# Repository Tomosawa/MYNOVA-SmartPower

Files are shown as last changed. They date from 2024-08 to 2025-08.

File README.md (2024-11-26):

<div id="top">
<p align="center">
  

  <h1 align="center">MYNOVA-SmartPower</h1>
</p>
</div>
<div align="center">








English | [简体中文](README_zh-CN.md) | [日本語](README_ja-JP.md)

</div>

# Introduction

This is an open-source hardware project aimed at creating an intelligent power extraction box for DELL server PSUs. It controls power switching, reads voltage, current, power values, and temperature inputs and displays them on an OLED screen. The device outputs 12V power through DC5.5 and XT60 interfaces for standard 12V devices.

The open-source project includes firmware code for the chip, web-based application code, circuit schematics (Altium Designer and PADS), and PCB Gerber files. Additionally, 3D files of the casing are provided for 3D printing.

Completed product can be seen in the following image:

<center>

<p float="left">
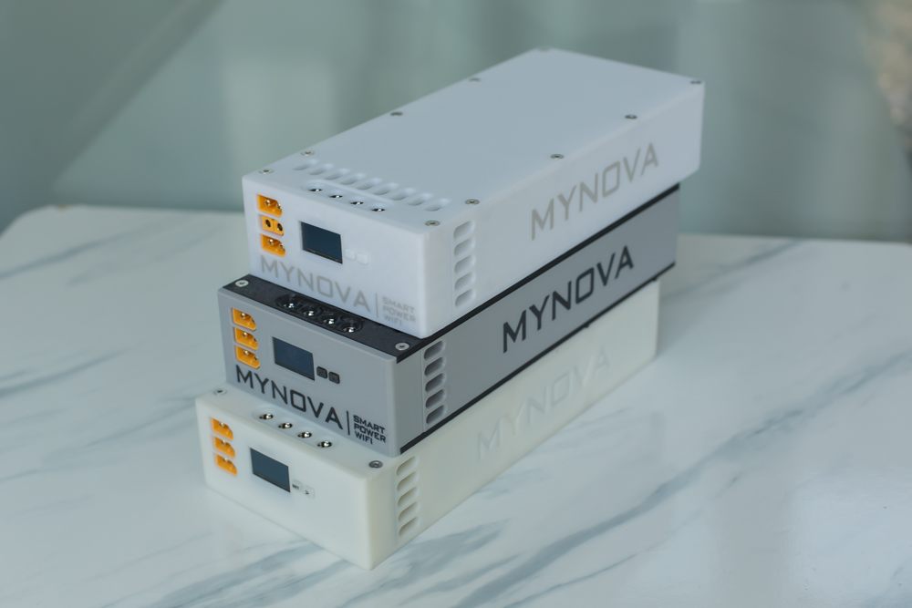
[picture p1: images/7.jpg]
  
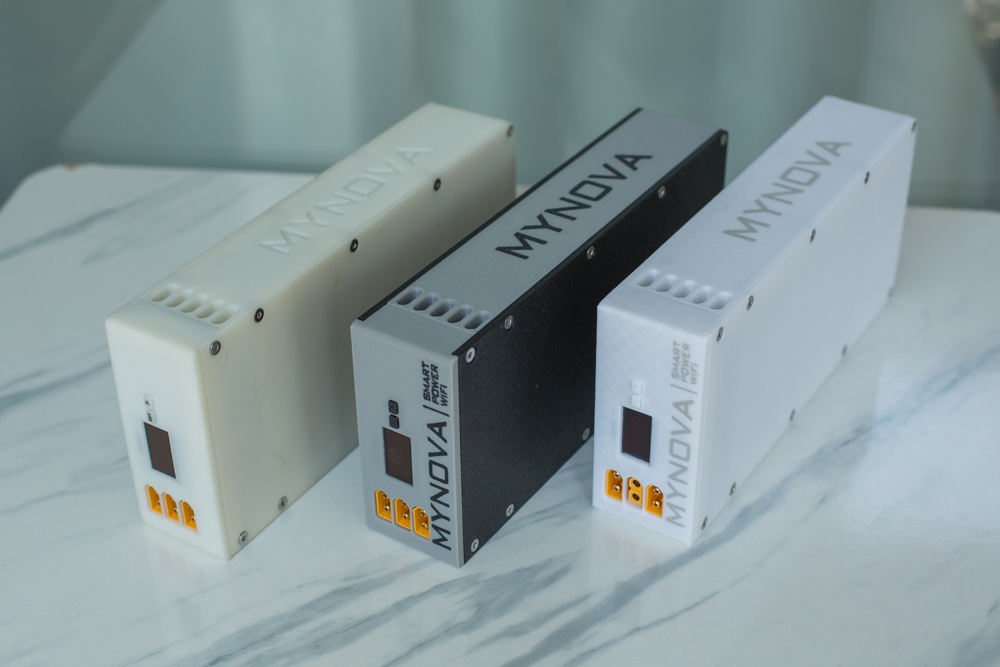
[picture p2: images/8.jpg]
  
</p>
<p float="left">
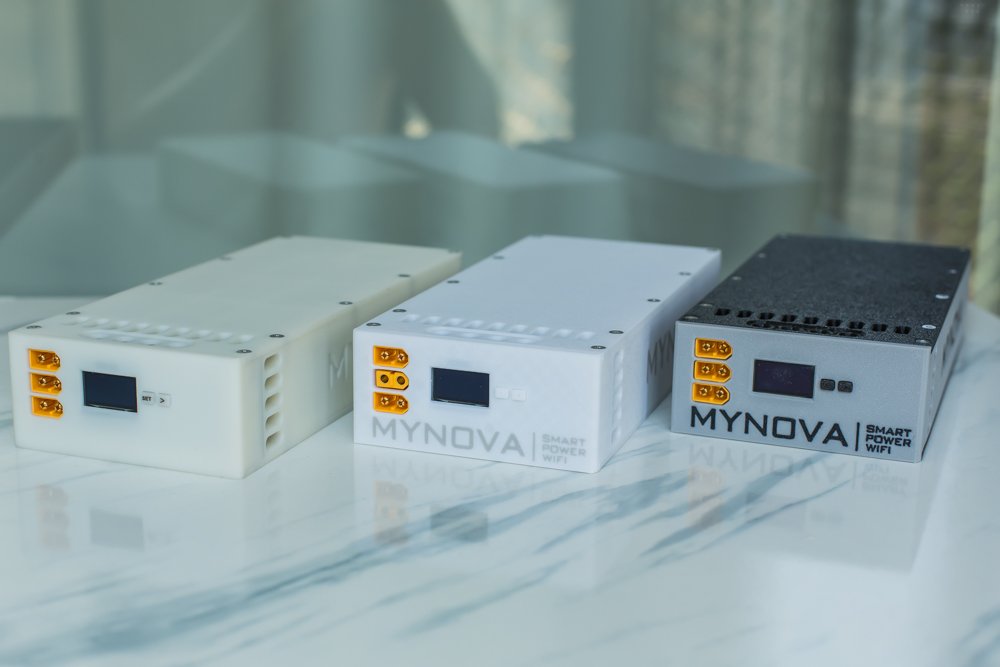
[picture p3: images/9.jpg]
  
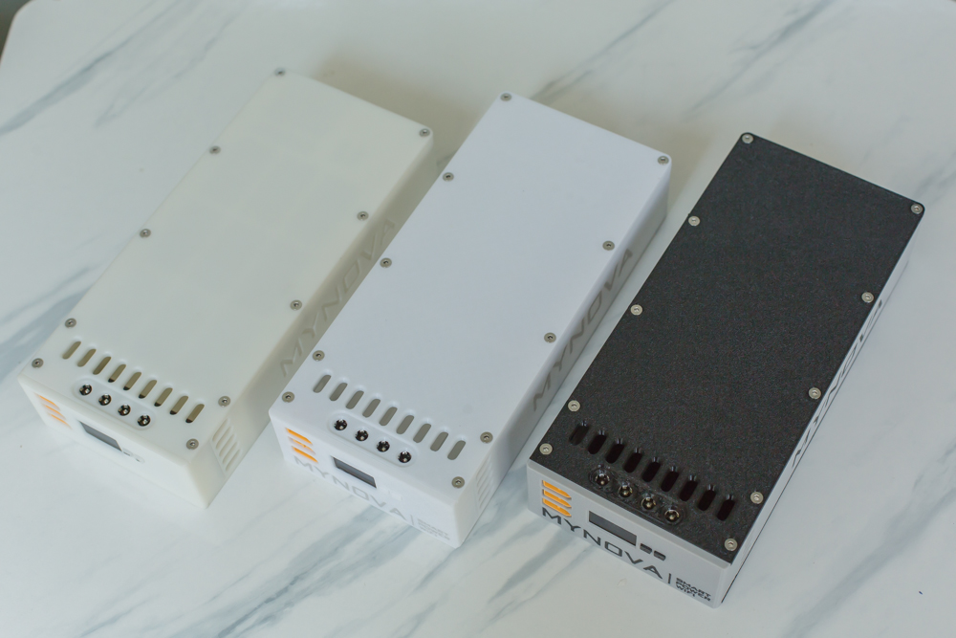
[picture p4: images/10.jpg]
  
</p>
<p float="left">
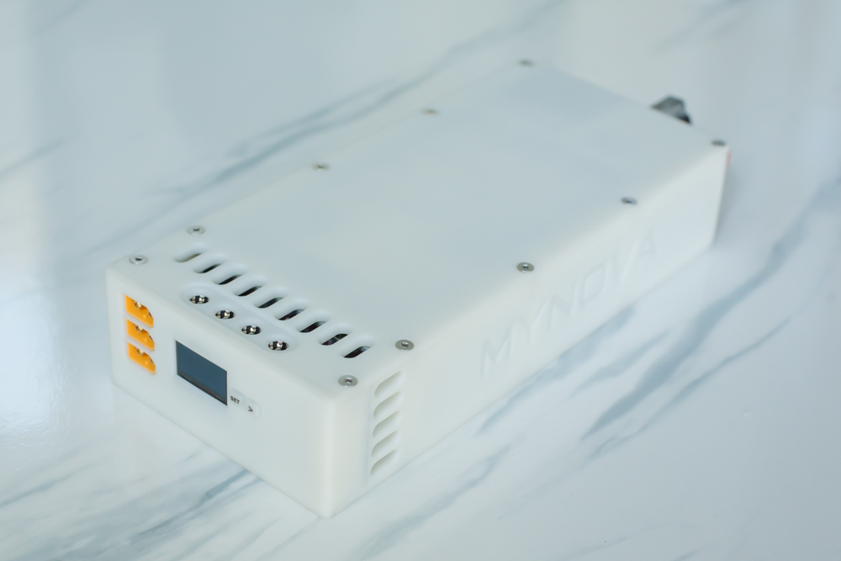
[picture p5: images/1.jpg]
  
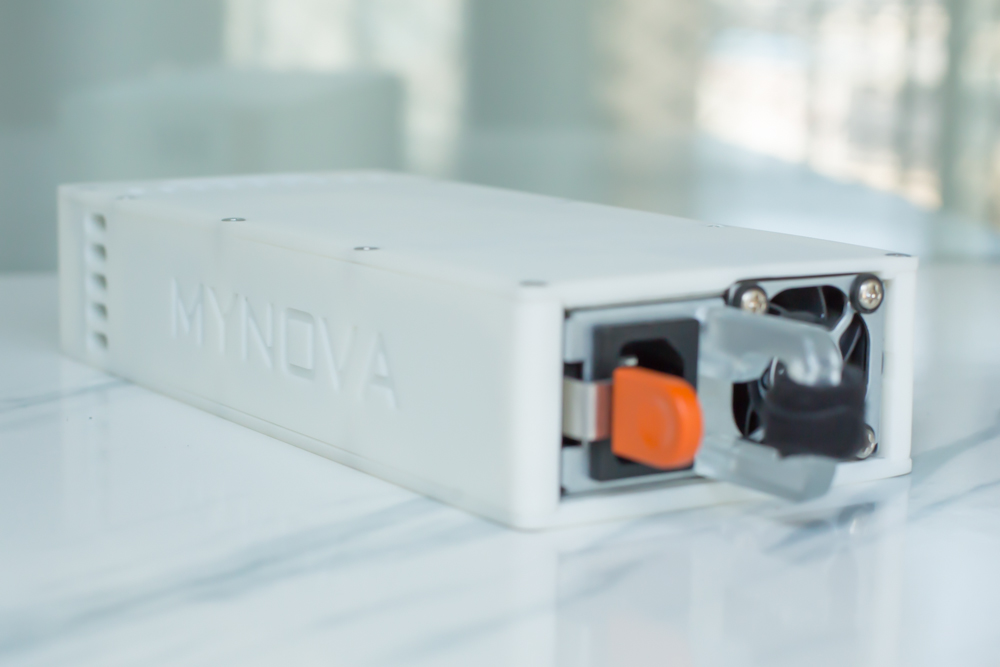
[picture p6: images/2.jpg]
  
</p>
<p float="left">
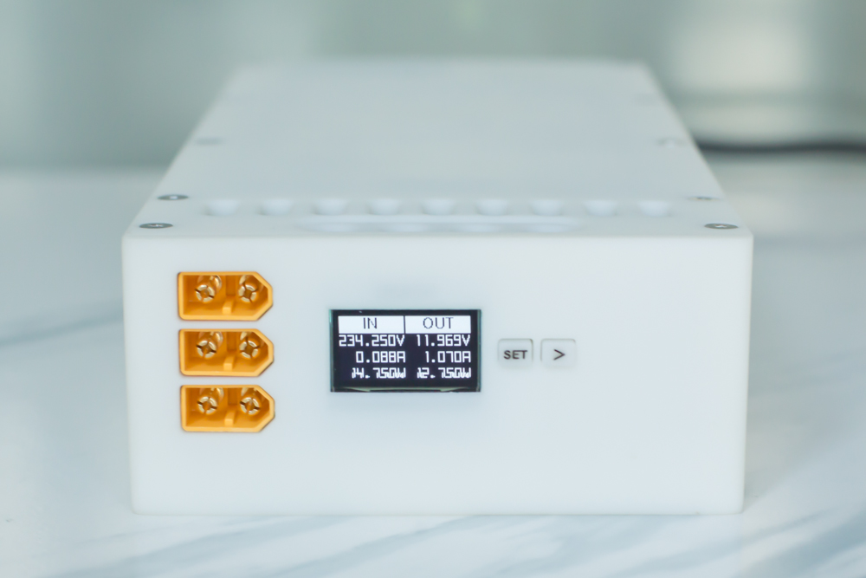
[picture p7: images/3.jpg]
  
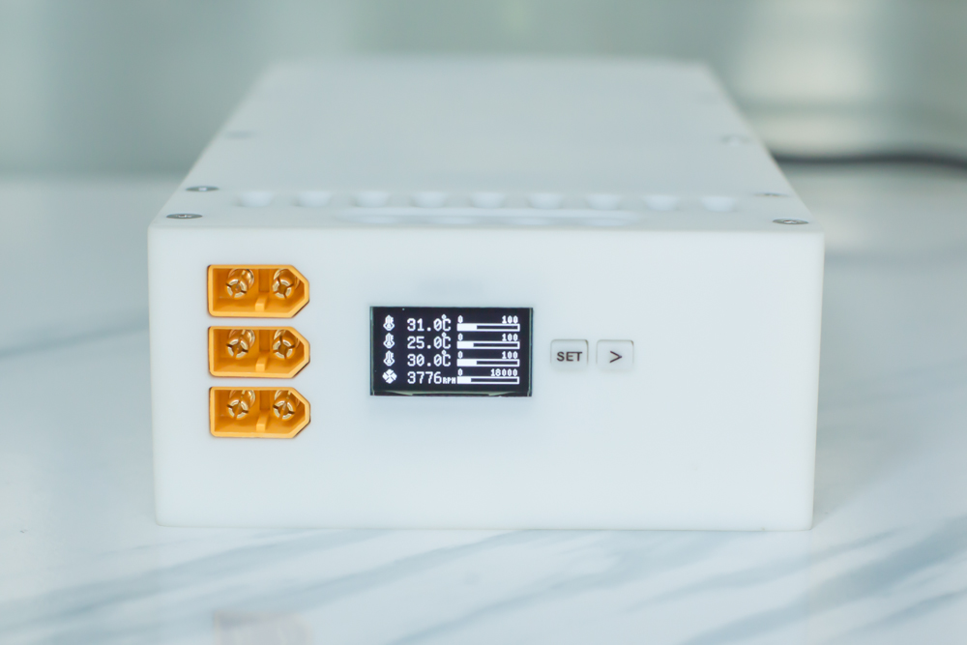
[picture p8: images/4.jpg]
  
</p>
<p float="left">
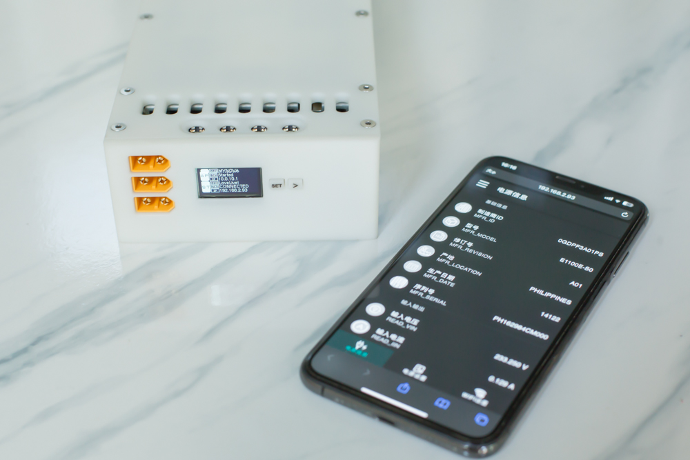
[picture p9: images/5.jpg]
  
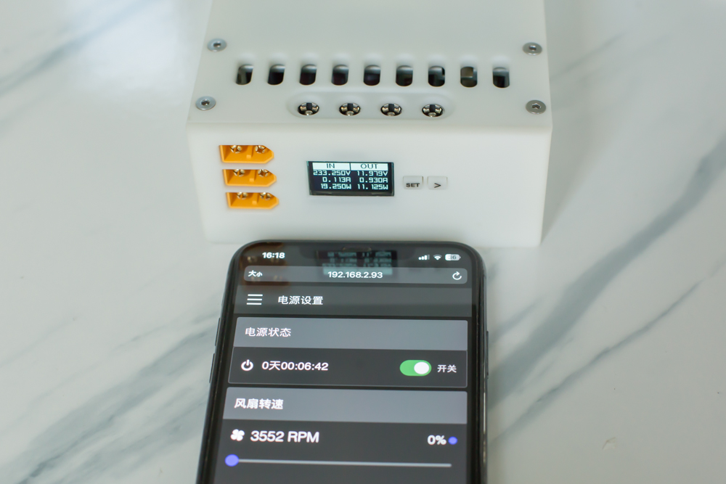
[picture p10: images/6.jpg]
  
</p>

</center>

## Features

- Control power on and off.
- Read and display input, output voltage, current, and power values.
- Read power supply temperature.
- Set fan speed (currently ineffective, overridden by the PSU itself).
- WiFi connectivity to view data via web interface by entering IP on mobile or computer.
- Control power on and off via web interface.

## New Features in V1.1 (20241126)
- Compatibility with E495E-S1 and E750E-S1 power supplies
- Added a settings page on the device end: Access by long-pressing the right key on the network page.
- Support for toggling WIFI on/off, hotspot on/off, and screen brightness settings
- Support for setting the device to automatically power on after being plugged in
- Countdown automatic shutdown feature
- Timed on/off feature, supporting time period settings for on/off, individual on or off, and repeat cycle strategy setup
- Conditional shutdown feature, which shuts down the device when the input or output current or power exceeds or falls below a certain value.

## Supported Chips

- ESP32-S3-WROOM-N16
- ESP32-S3-WROOM-N8

Or chips from the ESP32-S3 series. Depending on flash capacity of the chip, define partition table before download firmware.

## Tested PSU

This firmware has been tested on the following DELL PSU models:
- F495E-S0
- E750E-S0
- F750E-S0
- D750E-S2
- E1100E-S0
- L1100E-S0
- D2000E-S2(EPP)
- E495E-S1(EPP)
- E750E-S1(EPP)

Other models should be similar; further testing required as I lack additional models.

## Directory Structure

- MYNOVA_POWER: Firmware code for the chip.
- ESPVue: Web-related application code.
- partitions: Partition table files.
- Hardware: Hardware datasheet, including circuit schematics, design files for Altium Designer and PADS, as well as PCB Gerber files.
- 3DModels: 3D model files for the casing, including STL and editable STEP files.

## Compilation Environment

- Firmware: Arduino IDE 1.8.19
- Web: Node.js v20.15.1

## Firmware Dependencies

- Install ESP32 official development board (recommended V2.0.11 to avoid compilation failures).
- Install U8g2lib.
- Install ESPAsyncWebServer server component.
- Install ArduinoJson library.
- Install ESP32TimerInterrupt library.

## Firmware Flashing Method

1. Depending on the flash size of your ESP32-S3 chip (16MB or 8MB), download the corresponding bin file from the [Release](https://github.com/Tomosawa/MYNOVA-SmartPower/releases) page.
2. Download the official [flash download tools](https://www.espressif.com/en/support/download/other-tools) or use the [esptool.py](https://github.com/espressif/esptool) command line tool.
3. Select the appropriate `.bin` firmware file and set the flash offset address to `0x0000`.
4. Do not check the `DoNotChgBin` option, then click start to begin the flashing process.

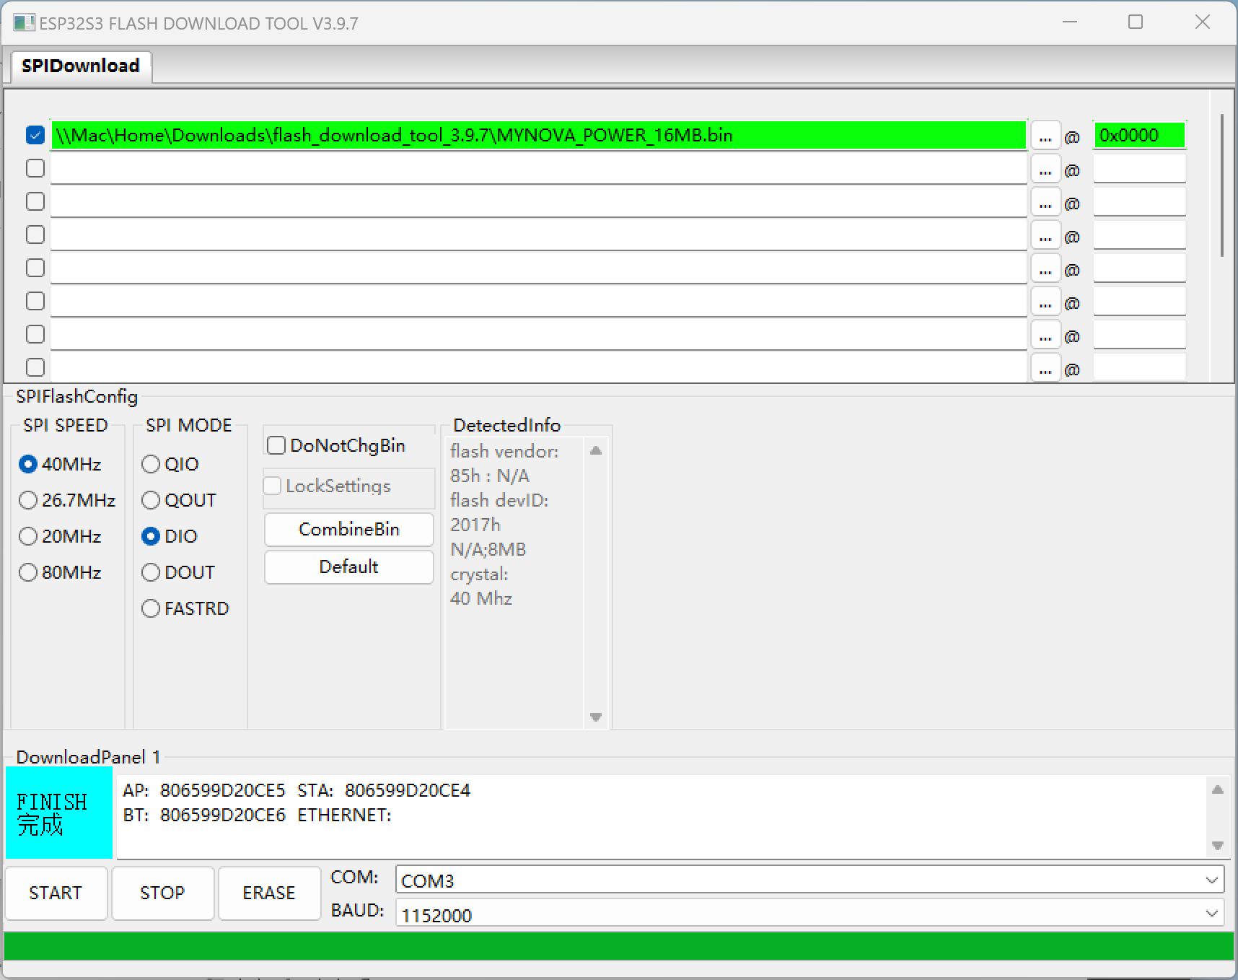
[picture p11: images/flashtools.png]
flashdownloadtools


## Contribution Guidelines

Contributions to this project are welcome. Please follow these guidelines:
- Fork the repository and create your feature branch.
- Commit your changes and push to your fork.
- Submit a Pull Request.

## Copyright Statement

This project is prohibited for any commercial use and is intended for learning and DIY purposes only.

## License [LICENSE](LICENSE)

This project is licensed under the [GPLv3](LICENSE). [GPLv3 (GNU General Public License version 3)](LICENSE) is a free, open-source software license that guarantees users the freedoms to run, study, share, and modify the software.
The complete text of the [GPLv3](LICENSE) license is included in the [LICENSE](LICENSE) file of this project. Before using, modifying, or distributing the code of this project, make sure you have read and understood the entire [GPLv3](LICENSE) license.

## Acknowledgments

- [Multibutton](https://github.com/0x1abin/MultiButton)

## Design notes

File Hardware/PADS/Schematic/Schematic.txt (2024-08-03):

*PADS-LOGIC-V9.0-CP936* from EasyEDA Pro
*SCH*
BORDER NAME Altium_A4
*SHT* 2 1_P1 -1 $$$NONE
*TEXT*
9600 4300 90 0 167 10 0 "Regular Times New Roman"
IO2
1650 3050 0 12 278 10 0 "Regular 宋体"
电源输入部分
8950 3100 0 12 278 10 0 "Regular 宋体"
单片机部分
4550 3100 0 12 278 10 0 "Regular 宋体"
开关及状态指示
1750 1950 0 12 278 10 0 "Regular 宋体"
OLED显示屏
5350 550 0 12 278 10 0 "Regular 宋体"
3.3V供电模块
9400 550 0 12 278 10 0 "Regular 宋体"
输出接口
1700 650 0 12 278 10 0 "Regular 宋体"
螺丝孔
550 2050 0 0 139 10 0 "Regular 宋体"
显示屏HS96L03W2C03需单独买
*LINES*
Altium_A4 LINES 0 0 6 43
CLOSED 5 10 255
0 7600
0 0
11500 0
11500 7600
0 7600
CLOSED 5 10 255
400 7200
400 400
11100 400
11100 7200
400 7200
OPEN 2 10 255
10781 0
10781 400
OPEN 2 10 255
10781 7200
10781 7600
OPEN 2 10 255
0 5700
400 5700
OPEN 2 10 255
11100 5700
11500 5700
359 200 0 12 125 10 0 "Regular Verdana"
1
359 7400 0 12 125 10 0 "Regular Verdana"
1
1078 200 0 12 125 10 0 "Regular Verdana"
2
1078 7400 0 12 125 10 0 "Regular Verdana"
2
1797 200 0 12 125 10 0 "Regular Verdana"
3
1797 7400 0 12 125 10 0 "Regular Verdana"
3
2516 200 0 12 125 10 0 "Regular Verdana"
4
2516 7400 0 12 125 10 0 "Regular Verdana"
4
3234 200 0 12 125 10 0 "Regular Verdana"
5
3234 7400 0 12 125 10 0 "Regular Verdana"
5
3953 200 0 12 125 10 0 "Regular Verdana"
6
3953 7400 0 12 125 10 0 "Regular Verdana"
6
4672 200 0 12 125 10 0 "Regular Verdana"
7
4672 7400 0 12 125 10 0 "Regular Verdana"
7
5391 200 0 12 125 10 0 "Regular Verdana"
8
5391 7400 0 12 125 10 0 "Regular Verdana"
8
6109 200 0 12 125 10 0 "Regular Verdana"
9
6109 7400 0 12 125 10 0 "Regular Verdana"
9
6828 200 0 12 125 10 0 "Regular Verdana"
10
6828 7400 0 12 125 10 0 "Regular Verdana"
10
7547 200 0 12 125 10 0 "Regular Verdana"
11
7547 7400 0 12 125 10 0 "Regular Verdana"
11
8266 200 0 12 125 10 0 "Regular Verdana"
12
8266 7400 0 12 125 10 0 "Regular Verdana"
12
8984 200 0 12 125 10 0 "Regular Verdana"
13
8984 7400 0 12 125 10 0 "Regular Verdana"
13
9703 200 0 12 125 10 0 "Regular Verdana"
14
9703 7400 0 12 125 10 0 "Regular Verdana"
14
10422 200 0 12 125 10 0 "Regular Verdana"
15
10422 7400 0 12 125 10 0 "Regular Verdana"
15
11141 200 0 12 125 10 0 "Regular Verdana"
16
11141 7400 0 12 125 10 0 "Regular Verdana"
16
200 950 0 12 125 10 0 "Regular Verdana"
D
11300 950 0 12 125 10 0 "Regular Verdana"
D
200 2850 0 12 125 10 0 "Regular Verdana"
C
11300 2850 0 12 125 10 0 "Regular Verdana"
C
200 4750 0 12 125 10 0 "Regular Verdana"
B
11300 4750 0 12 125 10 0 "Regular Verdana"
B
200 6650 0 12 125 10 0 "Regular Verdana"
A
11300 6650 0 12 125 10 0 "Regular Verdana"
A
0 -400 0 0 139 10 0 "Regular Times New Roman"
ModifiedDate : 2024/6/10
0 -300 0 0 139 10 0 "Regular Times New Roman"
Author : Tomosawa
0 -200 0 0 139 10 0 "Regular Times New Roman"
Title : 戴尔服务器电源取电板
$$Line1 LINES 0 0 1 0
OPEN 3 10 0
400 2900
2950 2900
2950 7200
$$Line2 LINES 0 0 1 0
OPEN 2 10 0
2950 2900
2955 405
$$Line3 LINES 0 0 1 0
OPEN 2 10 0
6850 7200
6850 2900
$$Line4 LINES 0 0 1 0
OPEN 2 10 0
7600 2900
7605 405
$$Line5 LINES 0 0 1 0
OPEN 2 10 0
2955 2905
11100 2900
$$Line6 LINES 0 0 1 0
OPEN 2 10 0
400 1750
2950 1750
*CAEDECAL*
PIN 0 0 100 10 100 10 2 1 0 0 0 1
TIMESTAMP 2024.08.03.20.45.55
"Default Font"
"Default Font"
0 0 0 0 94 6 0 "Regular default"
PART-TYPE
0 0 0 0 94 6 0 "Regular default"
REF-DES
OPEN 2 10 255
0 0
100 0
PIN_1 0 0 100 10 100 10 2 1 0 0 0 1
TIMESTAMP 2024.08.03.20.45.55
"Default Font"
"Default Font"
0 0 0 0 94 6 0 "Regular default"
PART-TYPE
0 0 0 0 94 6 0 "Regular default"
REF-DES
OPEN 2 10 255
0 0
200 0
PIN_2 0 0 100 10 100 10 2 1 0 0 0 1
TIMESTAMP 2024.08.03.20.45.55
"Default Font"
"Default Font"
0 0 0 0 94 6 0 "Regular default"
PART-TYPE
0 0 0 0 94 6 0 "Regular default"
REF-DES
OPEN 2 10 255
0 0
20 0
+12V 0 0 100 10 100 10 2 3 0 1 26 0
TIMESTAMP 2024.08.03.20.45.55
"Default Font"
"Default Font"
0 0 0 0 9 1 0 "Regular default"
PART-TYPE
0 0 0 0 9 1 0 "Regular default"
REF-DES
OPEN 2 10 255
0 0
100 0
OPEN 2 10 255
100 50
100 -50
OPEN 2 10 255
0 0
-0 -0
T0 0 90 2 0 10 0 4 10 -30 0 0 
P-100 0 0 1 0 0 0 0 128
+12VSB 0 0 100 10 100 10 2 3 0 1 26 0
TIMESTAMP 2024.08.03.20.45.55
"Default Font"
"Default Font"
0 0 0 0 9 1 0 "Regular default"
PART-TYPE
0 0 0 0 9 1 0 "Regular default"
REF-DES
OPEN 2 10 255
0 0
100 0
OPEN 2 10 255
100 50
100 -50
OPEN 2 10 255
0 0
-0 -0
T0 0 90 2 0 10 0 4 10 -30 0 0 
P-100 0 0 1 0 0 0 0 128
0603WAF2200T5E 0 0 100 10 100 10 2 1 0 2 0 0
TIMESTAMP 2024.08.03.20.45.55
"Default Font"
"Default Font"
0 0 0 0 14 10 0 "Regular 宋体"
PART-TYPE
0 0 0 0 14 10 0 "Regular 宋体"
REF-DES
CLOSED 5 10 255
-100 40
-100 -40
100 -40
100 40
-100 40
T200 0 0 1 50 10 0 4 110 -30 0 0 PIN
P-100 0 0 1 0 0 0 0 128
T-200 0 0 0 50 10 0 4 110 -30 0 0 PIN
P-100 0 0 1 0 0 0 0 128
100p 0 0 100 10 100 10 2 4 0 2 0 0
TIMESTAMP 2024.08.03.20.45.55
"Default Font"
"Default Font"
0 0 0 0 14 10 0 "Regular 宋体"
PART-TYPE
0 0 0 0 14 10 0 "Regular 宋体"
REF-DES
OPEN 2 10 255
-20 -80
-20 80
OPEN 2 10 255
100 0
20 0
OPEN 2 10 255
20 80
20 -80
OPEN 2 10 255
-20 0
-100 0
T-200 0 0 0 50 10 0 4 110 -30 0 0 PIN
P-100 0 0 1 0 0 0 0 128
T200 0 0 1 50 10 0 4 110 -30 0 0 PIN
P-100 0 0 1 0 0 0 0 128
10114587-001LF 0 0 100 10 100 10 2 1 0 60 0 0
TIMESTAMP 2024.08.03.20.45.55
"Default Font"
"Default Font"
0 0 0 0 9 1 0 "Regular default"
PART-TYPE
0 0 0 0 9 1 0 "Regular default"
REF-DES
CLOSED 5 10 255
-200 1600
-200 -1600
200 -1600
200 1600
-200 1600
T-400 1500 0 0 100 10 0 4 210 -30 0 0 PIN_1
P-100 0 0 1 0 0 0 0 128
T-400 1400 0 0 100 10 0 4 210 -30 0 0 PIN_1
P-100 0 0 1 0 0 0 0 128
T-400 1300 0 0 100 10 0 4 210 -30 0 0 PIN_1
P-100 0 0 1 0 0 0 0 128
T-400 1200 0 0 100 10 0 4 210 -30 0 0 PIN_1
P-100 0 0 1 0 0 0 0 128
T-400 1100 0 0 100 10 0 4 210 -30 0 0 PIN_1
P-100 0 0 1 0 0 0 0 128
T-400 1000 0 0 100 10 0 4 210 -30 0 0 PIN_1
P-100 0 0 1 0 0 0 0 128
T-400 900 0 0 100 10 0 4 210 -30 0 0 PIN_1
P-100 0 0 1 0 0 0 0 128
T-400 800 0 0 100 10 0 4 210 -30 0 0 PIN_1
P-100 0 0 1 0 0 0 0 128
T-400 700 0 0 100 10 0 4 210 -30 0 0 PIN_1
P-100 0 0 1 0 0 0 0 128
T-400 600 0 0 100 10 0 4 210 -30 0 0 PIN_1
P-100 0 0 1 0 0 0 0 128
T-400 500 0 0 100 10 0 4 210 -30 0 0 PIN_1
P-100 0 0 1 0 0 0 0 128
T-400 400 0 0 100 10 0 4 210 -30 0 0 PIN_1
P-100 0 0 1 0 0 0 0 128
T-400 300 0 0 100 10 0 4 210 -30 0 0 PIN_1
P-100 0 0 1 0 0 0 0 128
T-400 200 0 0 100 10 0 4 210 -30 0 0 PIN_1
P-100 0 0 1 0 0 0 0 128
T-400 100 0 0 100 10 0 4 210 -30 0 0 PIN_1
P-100 0 0 1 0 0 0 0 128
T-400 0 0 0 100 10 0 4 210 -30 0 0 PIN_1
P-100 0 0 1 0 0 0 0 128
T-400 -100 0 0 100 10 0 4 210 -30 0 0 PIN_1
P-100 0 0 1 0 0 0 0 128
T-400 -200 0 0 100 10 0 4 210 -30 0 0 PIN_1
P-100 0 0 1 0 0 0 0 128
T400 -200 0 1 100 10 0 4 210 -30 0 0 PIN_1
P-100 0 0 1 0 0 0 0 128
T400 -100 0 1 100 10 0 4 210 -30 0 0 PIN_1
P-100 0 0 1 0 0 0 0 128
T400 0 0 1 100 10 0 4 210 -30 0 0 PIN_1
P-100 0 0 1 0 0 0 0 128
T400 100 0 1 100 10 0 4 210 -30 0 0 PIN_1
P-100 0 0 1 0 0 0 0 128
T400 200 0 1 100 10 0 4 210 -30 0 0 PIN_1
P-100 0 0 1 0 0 0 0 128
T400 300 0 1 100 10 0 4 210 -30 0 0 PIN_1
P-100 0 0 1 0 0 0 0 128
T400 400 0 1 100 10 0 4 210 -30 0 0 PIN_1
P-100 0 0 1 0 0 0 0 128
T400 500 0 1 100 10 0 4 210 -30 0 0 PIN_1
P-100 0 0 1 0 0 0 0 128
T400 600 0 1 100 10 0 4 210 -30 0 0 PIN_1
P-100 0 0 1 0 0 0 0 128
T400 700 0 1 100 10 0 4 210 -30 0 0 PIN_1
P-100 0 0 1 0 0 0 0 128
T400 800 0 1 100 10 0 4 210 -30 0 0 PIN_1
P-100 0 0 1 0 0 0 0 128
T400 900 0 1 100 10 0 4 210 -30 0 0 PIN_1
P-100 0 0 1 0 0 0 0 128
T400 1000 0 1 100 10 0 4 210 -30 0 0 PIN_1
P-100 0 0 1 0 0 0 0 128
T400 1100 0 1 100 10 0 4 210 -30 0 0 PIN_1
P-100 0 0 1 0 0 0 0 128
T400 1200 0 1 100 10 0 4 210 -30 0 0 PIN_1
P-100 0 0 1 0 0 0 0 128
T400 1300 0 1 100 10 0 4 210 -30 0 0 PIN_1
P-100 0 0 1 0 0 0 0 128
T400 1400 0 1 100 10 0 4 210 -30 0 0 PIN_1
P-100 0 0 1 0 0 0 0 128
T400 1500 0 1 100 10 0 4 210 -30 0 0 PIN_1
P-100 0 0 1 0 0 0 0 128
T-400 -400 0 0 100 10 0 4 210 -30 0 0 PIN_1
P-100 0 0 1 0 0 0 0 128
T-400 -500 0 0 100 10 0 4 210 -30 0 0 PIN_1
P-100 0 0 1 0 0 0 0 128
T-400 -600 0 0 100 10 0 4 210 -30 0 0 PIN_1
P-100 0 0 1 0 0 0 0 128
T-400 -700 0 0 100 10 0 4 210 -30 0 0 PIN_1
P-100 0 0 1 0 0 0 0 128
T-400 -800 0 0 100 10 0 4 210 -30 0 0 PIN_1
P-100 0 0 1 0 0 0 0 128
T-400 -900 0 0 100 10 0 4 210 -30 0 0 PIN_1
P-100 0 0 1 0 0 0 0 128
T-400 -1000 0 0 100 10 0 4 210 -30 0 0 PIN_1
P-100 0 0 1 0 0 0 0 128
T-400 -1100 0 0 100 10 0 4 210 -30 0 0 PIN_1
P-100 0 0 1 0 0 0 0 128
T-400 -1200 0 0 100 10 0 4 210 -30 0 0 PIN_1
P-100 0 0 1 0 0 0 0 128
T-400 -1300 0 0 100 10 0 4 210 -30 0 0 PIN_1
P-100 0 0 1 0 0 0 0 128
T-400 -1400 0 0 100 10 0 4 210 -30 0 0 PIN_1
P-100 0 0 1 0 0 0 0 128
T-400 -1500 0 0 100 10 0 4 210 -30 0 0 PIN_1
P-100 0 0 1 0 0 0 0 128
T400 -1500 0 1 100 10 0 4 210 -30 0 0 PIN_1
P-100 0 0 1 0 0 0 0 128
T400 -1400 0 1 100 10 0 4 210 -30 0 0 PIN_1
P-100 0 0 1 0 0 0 0 128
T400 -1300 0 1 100 10 0 4 210 -30 0 0 PIN_1
P-100 0 0 1 0 0 0 0 128
T400 -1200 0 1 100 10 0 4 210 -30 0 0 PIN_1
P-100 0 0 1 0 0 0 0 128
T400 -1100 0 1 100 10 0 4 210 -30 0 0 PIN_1
P-100 0 0 1 0 0 0 0 128
T400 -1000 0 1 100 10 0 4 210 -30 0 0 PIN_1
P-100 0 0 1 0 0 0 0 128
T400 -900 0 1 100 10 0 4 210 -30 0 0 PIN_1
P-100 0 0 1 0 0 0 0 128
T400 -800 0 1 100 10 0 4 210 -30 0 0 PIN_1
P-100 0 0 1 0 0 0 0 128
T400 -700 0 1 100 10 0 4 210 -30 0 0 PIN_1
P-100 0 0 1 0 0 0 0 128
T400 -600 0 1 100 10 0 4 210 -30 0 0 PIN_1
P-100 0 0 1 0 0 0 0 128
T400 -500 0 1 100 10 0 4 210 -30 0 0 PIN_1
P-100 0 0 1 0 0 0 0 128
T400 -400 0 1 100 10 0 4 210 -30 0 0 PIN_1
P-100 0 0 1 0 0 0 0 128
2.54-1*4P母 0 0 100 10 100 10 2 2 0 4 0 0
TIMESTAMP 2024.08.03.20.45.55
"Default Font"
"Default Font"
0 0 0 0 14 10 0 "Regular 宋体"
PART-TYPE
0 0 0 0 14 10 0 "Regular 宋体"
REF-DES
CLOSED 5 10 255
-100 250
-100 -250
100 -250
100 250
-100 250
CIRCLE 2 10 255
-35 200
-65 200
T-200 150 0 0 50 10 0 4 110 -30 0 0 PIN
P-100 0 0 1 0 0 0 0 128
T-200 50 0 0 50 10 0 4 110 -30 0 0 PIN
P-100 0 0 1 0 0 0 0 128
T-200 -50 0 0 50 10 0 4 110 -30 0 0 PIN
P-100 0 0 1 0 0 0 0 128
T-200 -150 0 0 50 10 0 4 110 -30 0 0 PIN
P-100 0 0 1 0 0 0 0 128
Cap 0 0 100 10 100 10 2 4 0 2 0 0
TIMESTAMP 2024.08.03.20.45.55
"Default Font"
"Default Font"
0 0 0 0 9 1 0 "Regular default"
PART-TYPE
0 0 0 0 9 1 0 "Regular default"
REF-DES
OPEN 2 10 255
70 -20
70 -180
OPEN 2 10 255
30 -180
30 -20
OPEN 2 10 255
0 -100
30 -100
OPEN 2 10 255
100 -100
70 -100
T-100 -100 0 0 50 10 0 4 110 -30 0 0 PIN
P-100 0 0 1 0 0 0 0 128
T200 -100 0 1 50 10 0 4 110 -30 0 0 PIN
P-100 0 0 1 0 0 0 0 128
CapAcitance 0 0 100 10 100 10 2 4 0 2 0 0
TIMESTAMP 2024.08.03.20.45.55
"Default Font"
"Default Font"
0 0 0 0 9 1 0 "Regular default"
PART-TYPE
0 0 0 0 9 1 0 "Regular default"
REF-DES
OPEN 2 10 255
-20 -80
-20 80
OPEN 2 10 255
100 0
20 0
OPEN 2 10 255
20 80
20 -80
OPEN 2 10 255
-20 0
-100 0
T-200 0 0 0 50 10 0 4 110 -30 0 0 PIN
P-100 0 0 1 0 0 0 0 128
T200 0 0 1 50 10 0 4 110 -30 0 0 PIN
P-100 0 0 1 0 0 0 0 128
CC0603JRNPO9BN101 0 0 100 10 100 10 2 4 0 2 0 0
TIMESTAMP 2024.08.03.20.45.55
"Default Font"
"Default Font"
0 0 0 0 14 10 0 "Regular 宋体"
PART-TYPE
0 0 0 0 14 10 0 "Regular 宋体"
REF-DES
OPEN 2 10 255
-20 -80
-20 80
OPEN 2 10 255
100 0
20 0
OPEN 2 10 255
20 80
20 -80
OPEN 2 10 255
-20 0
-100 0
T-200 0 0 0 50 10 0 4 110 -30 0 0 PIN
P-100 0 0 1 0 0 0 0 128
T200 0 0 1 50 10 0 4 110 -30 0 0 PIN
P-100 0 0 1 0 0 0 0 128
CL21A476MQYNNNE 0 0 100 10 100 10 2 4 0 2 0 0
TIMESTAMP 2024.08.03.20.45.55
"Default Font"
"Default Font"
0 0 0 0 14 10 0 "Regular 宋体"
PART-TYPE
0 0 0 0 14 10 0 "Regular 宋体"
REF-DES
OPEN 2 10 255
-20 80
-20 -80
OPEN 2 10 255
20 80
20 -80
OPEN 2 10 255
-50 0
-20 0
OPEN 2 10 255
20 0
50 0
T-150 0 0 0 50 10 0 4 110 -30 0 0 PIN
P-100 0 0 1 0 0 0 0 128
T150 0 0 1 50 10 0 4 110 -30 0 0 PIN
P-100 0 0 1 0 0 0 0 128
CSPS_PROK 0 0 100 10 100 10 2 2 0 1 0 0
TIMESTAMP 2024.08.03.20.45.55
"Default Font"
"Default Font"
0 0 0 0 9 1 0 "Regular default"
PART-TYPE
0 0 0 0 9 1 0 "Regular default"
REF-DES
CLOSED 10 10 255
50 -50
0 0
0 0
50 50
50 50
720 50
720 50
720 -50
720 -50
50 -50
OPEN 2 10 255
0 0
-0 -0
T0 0 90 2 0 10 0 4 10 -30 0 0 
P-100 0 0 1 0 0 0 0 128
CSPS_PROK_1 0 0 100 10 100 10 2 2 0 1 0 0
TIMESTAMP 2024.08.03.20.45.55
"Default Font"
"Default Font"
0 0 0 0 9 1 0 "Regular default"
PART-TYPE
0 0 0 0 9 1 0 "Regular default"
REF-DES
CLOSED 10 10 255
0 -50
0 50
0 50
670 50
670 50
720 0
720 0
670 -50
670 -50
0 -50
OPEN 2 10 255
720 0
720 -0
T720 0 90 2 0 10 0 4 10 -30 0 0 
P-100 0 0 1 0 0 0 0 128
CSPS_PSON 0 0 100 10 100 10 2 2 0 1 0 0
TIMESTAMP 2024.08.03.20.45.55
"Default Font"
"Default Font"
0 0 0 0 9 1 0 "Regular default"
PART-TYPE
0 0 0 0 9 1 0 "Regular default"
REF-DES
CLOSED 10 10 255
50 -50
0 0
0 0
50 50
50 50
720 50
720 50
720 -50
720 -50
50 -50
OPEN 2 10 255
0 0
-0 -0
T0 0 90 2 0 10 0 4 10 -30 0 0 
P-100 0 0 1 0 0 0 0 128
CSPS_PSON_1 0 0 100 10 100 10 2 2 0 1 0 0
TIMESTAMP 2024.08.03.20.45.55
"Default Font"
"Default Font"
0 0 0 0 9 1 0 "Regular default"
PART-TYPE
0 0 0 0 9 1 0 "Regular default"
REF-DES
CLOSED 10 10 255
0 -50
0 50
0 50
670 50
670 50
720 0
720 0
670 -50
670 -50
0 -50
OPEN 2 10 255
720 0
720 -0
T720 0 90 2 0 10 0 4 10 -30 0 0 
P-100 0 0 1 0 0 0 0 128
DC-091-A250 0 0 100 10 100 10 2 6 0 3 0 0
TIMESTAMP 2024.08.03.20.45.55
"Default Font"
"Default Font"
0 0 0 0 14 10 0 "Regular 宋体"
PART-TYPE
0 0 0 0 14 10 0 "Regular 宋体"
REF-DES
OPEN 2 10 255
100 0
40 0
OPEN 2 10 255
0 40
-200 40
OPEN 2 10 255
0 -40
-200 -40
OPEN 6 10 255
100 -100
-190 -100
-190 -100
-210 -60
-210 -60
-230 -100
CLOSED 5 10 255
0 60
0 -60
40 -60
40 60
0 60
OPEN 2 10 255
-200 -40 2700 -1800 -240 -40 -160 40
-200 40
T300 0 0 1 100 10 0 4 210 -30 0 0 PIN_1
P-100 0 0 1 0 0 0 0 128
T300 -100 0 1 100 10 0 4 210 -30 0 0 PIN_1
P-100 0 0 1 0 0 0 0 128
T300 100 0 1 100 10 0 4 210 -30 0 0 PIN_1
P-100 0 0 1 0 0 0 0 128
ESP32-S3-WROOM-1(N16) 0 0 100 10 100 10 2 4 0 41 0 0
TIMESTAMP 2024.08.03.20.45.55
"Default Font"
"Default Font"
0 0 0 0 9 1 0 "Regular default"
PART-TYPE
0 0 0 0 9 1 0 "Regular default"
REF-DES
CLOSED 5 10 255
-800 1450
-800 -1300
800 -1300
800 1450
-800 1450
OPEN 2 10 255
800 750
-800 750
OPEN 74 10 255
-600 900
-600 1300
-600 1300
-600 1300
-600 1300
-600 1300
-600 1300
-600 1300
-600 1300
-400 1300
-400 1300
-400 1300
-400 1300
-400 1300
-400 1300
-400 1300
-400 1300
-400 1050
-400 1050
-400 1050
-400 1050
-400 1050
-400 1050
-400 1050
-400 1050
-150 1050
-150 1050
-150 1050
-150 1050
-150 1050
-150 1050
-150 1050
-150 1050
-150 1300
-150 1300
-150 1300
-150 1300
-150 1300
-150 1300
-150 1300
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
CIRCLE 2 10 255
-735 500
-765 500
T-900 400 0 0 50 10 0 4 110 -30 0 0 PIN
P-100 0 0 1 0 0 0 0 128
T-900 300 0 0 50 10 0 4 110 -30 0 0 PIN
P-100 0 0 1 0 0 0 0 128
T-900 200 0 0 50 10 0 4 110 -30 0 0 PIN
P-100 0 0 1 0 0 0 0 128
T-900 100 0 0 50 10 0 4 110 -30 0 0 PIN
P-100 0 0 1 0 0 0 0 128
T-900 0 0 0 50 10 0 4 110 -30 0 0 PIN
P-100 0 0 1 0 0 0 0 128
T-900 -100 0 0 50 10 0 4 110 -30 0 0 PIN
P-100 0 0 1 0 0 0 0 128
T-900 -200 0 0 50 10 0 4 110 -30 0 0 PIN
P-100 0 0 1 0 0 0 0 128
T-900 -300 0 0 50 10 0 4 110 -30 0 0 PIN
P-100 0 0 1 0 0 0 0 128
T-900 -400 0 0 50 10 0 4 110 -30 0 0 PIN
P-100 0 0 1 0 0 0 0 128
T-900 -500 0 0 50 10 0 4 110 -30 0 0 PIN
P-100 0 0 1 0 0 0 0 128
T-900 -600 0 0 50 10 0 4 110 -30 0 0 PIN
P-100 0 0 1 0 0 0 0 128
T-900 -700 0 0 50 10 0 4 110 -30 0 0 PIN
P-100 0 0 1 0 0 0 0 128
T-900 -800 0 0 50 10 0 4 110 -30 0 0 PIN
P-100 0 0 1 0 0 0 0 128
T-900 -900 0 0 50 10 0 4 110 -30 0 0 PIN
P-100 0 0 1 0 0 0 0 128
T-500 -1400 90 0 50 10 0 4 110 -30 0 0 PIN
P-100 0 0 1 0 0 0 0 128
T-400 -1400 90 0 50 10 0 4 110 -30 0 0 PIN
P-100 0 0 1 0 0 0 0 128
T-300 -1400 90 0 50 10 0 4 110 -30 0 0 PIN
P-100 0 0 1 0 0 0 0 128
T-200 -1400 90 0 50 10 0 4 110 -30 0 0 PIN
P-100 0 0 1 0 0 0 0 128
T-100 -1400 90 0 50 10 0 4 110 -30 0 0 PIN
P-100 0 0 1 0 0 0 0 128
T0 -1400 90 0 50 10 0 4 110 -30 0 0 PIN
P-100 0 0 1 0 0 0 0 128
T100 -1400 90 0 50 10 0 4 110 -30 0 0 PIN
P-100 0 0 1 0 0 0 0 128
T200 -1400 90 0 50 10 0 4 110 -30 0 0 PIN
P-100 0 0 1 0 0 0 0 128
T300 -1400 90 0 50 10 0 4 110 -30 0 0 PIN
P-100 0 0 1 0 0 0 0 128
T400 -1400 90 0 50 10 0 4 110 -30 0 0 PIN
P-100 0 0 1 0 0 0 0 128
T500 -1400 90 0 50 10 0 4 110 -30 0 0 PIN
P-100 0 0 1 0 0 0 0 128
T600 -1400 90 0 50 10 0 4 110 -30 0 0 PIN
P-100 0 0 1 0 0 0 0 128
T900 -900 0 1 50 10 0 4 110 -30 0 0 PIN
P-100 0 0 1 0 0 0 0 128
T900 -800 0 1 50 10 0 4 110 -30 0 0 PIN
P-100 0 0 1 0 0 0 0 128
T900 -700 0 1 50 10 0 4 110 -30 0 0 PIN
P-100 0 0 1 0 0 0 0 128
T900 -600 0 1 50 10 0 4 110 -30 0 0 PIN
P-100 0 0 1 0 0 0 0 128
T900 -500 0 1 50 10 0 4 110 -30 0 0 PIN
P-100 0 0 1 0 0 0 0 128
T900 -400 0 1 50 10 0 4 110 -30 0 0 PIN
P-100 0 0 1 0 0 0 0 128
T900 -300 0 1 50 10 0 4 110 -30 0 0 PIN
P-100 0 0 1 0 0 0 0 128
T900 -200 0 1 50 10 0 4 110 -30 0 0 PIN
P-100 0 0 1 0 0 0 0 128
T900 -100 0 1 50 10 0 4 110 -30 0 0 PIN
P-100 0 0 1 0 0 0 0 128
T900 0 0 1 50 10 0 4 110 -30 0 0 PIN
P-100 0 0 1 0 0 0 0 128
T900 100 0 1 50 10 0 4 110 -30 0 0 PIN
P-100 0 0 1 0 0 0 0 128
T900 200 0 1 50 10 0 4 110 -30 0 0 PIN
P-100 0 0 1 0 0 0 0 128
T900 300 0 1 50 10 0 4 110 -30 0 0 PIN
P-100 0 0 1 0 0 0 0 128
T900 400 0 1 50 10 0 4 110 -30 0 0 PIN
P-100 0 0 1 0 0 0 0 128
T900 500 0 1 50 10 0 4 110 -30 0 0 PIN
P-100 0 0 1 0 0 0 0 128
GND 0 0 100 10 100 10 2 3 0 1 26 0
TIMESTAMP 2024.08.03.20.45.55
"Default Font"
"Default Font"
0 0 0 0 9 1 0 "Regular default"
PART-TYPE
0 0 0 0 9 1 0 "Regular default"
REF-DES
OPEN 2 10 255
0 0
100 0
OPEN 2 10 255
100 50
100 -50
OPEN 2 10 255
0 0
-0 -0
T0 0 90 2 0 10 0 4 10 -30 0 0 
P-100 0 0 1 0 0 0 0 128
INDUCTOR 0 0 100 10 100 10 2 4 0 2 0 0
TIMESTAMP 2024.08.03.20.45.55
"Default Font"
"Default Font"
0 0 0 0 9 1 0 "Regular default"
PART-TYPE
0 0 0 0 9 1 0 "Regular default"
REF-DES
OPEN 2 10 255
150 -50 0 900 50 -100 150 0
100 -0
OPEN 2 10 255
100 -100 2700 900 50 -100 150 0
150 -50
OPEN 2 10 255
150 -150 0 900 50 -200 150 -100
100 -100
OPEN 2 10 255
100 -200 2700 900 50 -200 150 -100
150 -150
T100 100 90 2 50 10 0 4 110 -30 0 0 PIN
P-100 0 0 1 0 0 0 0 128
T100 -300 90 0 50 10 0 4 110 -30 0 0 PIN
P-100 0 0 1 0 0 0 0 128
MT1470 0 0 100 10 100 10 2 1 0 6 0 0
TIMESTAMP 2024.08.03.20.45.55
"Default Font"
"Default Font"
0 0 0 0 9 1 0 "Regular default"
PART-TYPE
0 0 0 0 9 1 0 "Regular default"
REF-DES
CLOSED 5 10 255
-250 200
-250 -200
250 -200
250 200
-250 200
T350 100 0 1 50 10 0 4 110 -30 0 0 PIN
P-100 0 0 1 0 0 0 0 128
T350 -100 0 1 50 10 0 4 110 -30 0 0 PIN
P-100 0 0 1 0 0 0 0 128
T350 0 0 1 50 10 0 4 110 -30 0 0 PIN
P-100 0 0 1 0 0 0 0 128
T-350 -100 0 0 50 10 0 4 110 -30 0 0 PIN
P-100 0 0 1 0 0 0 0 128
T-350 0 0 0 50 10 0 4 110 -30 0 0 PIN
P-100 0 0 1 0 0 0 0 128
T-350 100 0 0 50 10 0 4 110 -30 0 0 PIN
P-100 0 0 1 0 0 0 0 128
NPN 0 0 100 10 100 10 2 7 0 3 0 0
TIMESTAMP 2024.08.03.20.45.55
"Default Font"
"Default Font"
0 0 0 0 9 1 0 "Regular default"
PART-TYPE
0 0 0 0 9 1 0 "Regular default"
REF-DES
OPEN 2 10 255
150 -240
240 -330
OPEN 2 10 255
300 -380
300 -400
OPEN 2 10 255
0 -200
150 -200
OPEN 4 10 255
300 0
300 -30
300 -30
150 -180
CLOSED 8 10 255
150 -70
130 -70
130 -70
130 -330
130 -330
150 -330
150 -330
150 -70
CLOSED 6 10 255
260 -310
220 -350
220 -350
300 -380
300 -380
260 -310
CIRCLE 2 10 255
400 -200
0 -200
T-200 -200 0 0 100 10 0 4 210 -30 0 0 PIN_1
P-100 0 0 1 0 0 0 0 128
T300 200 90 2 100 10 0 4 210 -30 0 0 PIN_1
P-100 0 0 1 0 0 0 0 128
T300 -600 90 0 100 10 0 4 210 -30 0 0 PIN_1
P-100 0 0 1 0 0 0 0 128
PRESENT 0 0 100 10 100 10 2 2 0 1 0 0
TIMESTAMP 2024.08.03.20.45.55
"Default Font"
"Default Font"
0 0 0 0 9 1 0 "Regular default"
PART-TYPE
0 0 0 0 9 1 0 "Regular default"
REF-DES
CLOSED 10 10 255
0 -50
0 50
0 50
510 50
510 50
560 0
560 0
510 -50
510 -50
0 -50
OPEN 2 10 255
560 0
560 -0
T560 0 90 2 0 10 0 4 10 -30 0 0 
P-100 0 0 1 0 0 0 0 128
PZ200V-11-06P 0 0 100 10 100 10 2 2 0 6 0 0
TIMESTAMP 2024.08.03.20.45.55
"Default Font"
"Default Font"
0 0 0 0 9 1 0 "Regular default"
PART-TYPE
0 0 0 0 9 1 0 "Regular default"
REF-DES
CLOSED 5 10 255
-100 350
-100 -350
100 -350
100 350
-100 350
CIRCLE 2 10 255
-35 300
-65 300
T-200 250 0 0 50 10 0 4 110 -30 0 0 PIN
P-100 0 0 1 0 0 0 0 128
T-200 150 0 0 50 10 0 4 110 -30 0 0 PIN
P-100 0 0 1 0 0 0 0 128
T-200 50 0 0 50 10 0 4 110 -30 0 0 PIN
P-100 0 0 1 0 0 0 0 128
T-200 -50 0 0 50 10 0 4 110 -30 0 0 PIN
P-100 0 0 1 0 0 0 0 128
T-200 -150 0 0 50 10 0 4 110 -30 0 0 PIN
P-100 0 0 1 0 0 0 0 128
T-200 -250 0 0 50 10 0 4 110 -30 0 0 PIN
P-100 0 0 1 0 0 0 0 128
Res2 0 0 100 10 100 10 2 1 0 2 0 0
TIMESTAMP 2024.08.03.20.45.55
"Default Font"
"Default Font"
0 0 0 0 9 1 0 "Regular default"
PART-TYPE
0 0 0 0 9 1 0 "Regular default"
REF-DES
CLOSED 5 10 255
0 -60
0 -140
200 -140
200 -60
0 -60
T300 -100 0 1 50 10 0 4 110 -30 0 0 PIN
P-100 0 0 1 0 0 0 0 128
T-100 -100 0 0 50 10 0 4 110 -30 0 0 PIN
P-100 0 0 1 0 0 0 0 128
SMAJ15CA_C1509527 0 0 100 10 100 10 2 3 0 2 0 0
TIMESTAMP 2024.08.03.20.45.55
"Default Font"
"Default Font"
0 0 0 0 14 10 0 "Regular 宋体"
PART-TYPE
0 0 0 0 14 10 0 "Regular 宋体"
REF-DES
OPEN 10 10 255
-20 80
-20 80
-20 80
0 60
0 60
0 -60
0 -60
10 -70
10 -70
20 -80
CLOSED 6 10 255
100 50
0 0
0 0
100 -50
100 -50
100 50
CLOSED 6 10 255
-100 50
0 0
0 0
-100 -50
-100 -50
-100 50
T-200 0 0 0 50 10 0 4 110 -30 0 0 PIN
P-100 0 0 1 0 0 0 0 128
T200 0 0 1 50 10 0 4 110 -30 0 0 PIN
P-100 0 0 1 0 0 0 0 128
TS-1088-AR02016 0 0 100 10 100 10 2 5 0 2 0 0
TIMESTAMP 2024.08.03.20.45.55
"Default Font"
"Default Font"
0 0 0 0 14 10 0 "Regular 宋体"
PART-TYPE
0 0 0 0 14 10 0 "Regular 宋体"
REF-DES
OPEN 2 10 255
-90 20
80 70
OPEN 2 10 255
200 0
100 0
OPEN 2 10 255
-200 0
-100 0
CIRCLE 2 10 255
100 0
60 0
CIRCLE 2 10 255
-60 0
-100 0
T300 0 0 1 50 10 0 4 110 -30 0 0 PIN
P-100 0 0 1 0 0 0 0 128
T-300 0 0 0 50 10 0 4 110 -30 0 0 PIN
P-100 0 0 1 0 0 0 0 128
VC060303A100DP 0 0 100 10 100 10 2 2 0 2 0 0
TIMESTAMP 2024.08.03.20.45.55
"Default Font"
"Default Font"
0 0 0 0 9 10 0 "Regular 宋体"
PART-TYPE
0 0 0 0 9 10 0 "Regular 宋体"
REF-DES
CLOSED 5 10 255
-200 50
-200 -50
0 -50
0 50
-200 50
OPEN 4 10 255
-200 -80
-150 -80
-150 -80
0 80
T-300 0 0 0 50 10 0 4 110 -30 0 0 PIN
P-100 0 0 1 0 0 0 0 128
T100 0 0 1 50 10 0 4 110 -30 0 0 PIN
P-100 0 0 1 0 0 0 0 128
VCC_3V3 0 0 100 10 100 10 2 3 0 1 26 0
TIMESTAMP 2024.08.03.20.45.55
"Default Font"
"Default Font"
0 0 0 0 9 1 0 "Regular default"
PART-TYPE
0 0 0 0 9 1 0 "Regular default"
REF-DES
OPEN 2 10 255
0 0
100 0
OPEN 2 10 255
100 50
100 -50
OPEN 2 10 255
0 0
-0 -0
T0 0 90 2 0 10 0 4 10 -30 0 0 
P-100 0 0 1 0 0 0 0 128
XT60 0 0 100 10 100 10 2 2 0 2 0 0
TIMESTAMP 2024.08.03.20.45.55
"Default Font"
"Default Font"
0 0 0 0 14 10 0 "Regular 宋体"
PART-TYPE
0 0 0 0 14 10 0 "Regular 宋体"
REF-DES
CLOSED 5 10 255
-100 150
-100 -150
100 -150
100 150
-100 150
CIRCLE 2 10 255
-35 100
-65 100
T-200 50 0 0 50 10 0 4 110 -30 0 0 PIN
P-100 0 0 1 0 0 0 0 128
T-200 -50 0 0 50 10 0 4 110 -30 0 0 PIN
P-100 0 0 1 0 0 0 0 128
电阻 0 0 100 10 100 10 2 1 0 2 0 0
TIMESTAMP 2024.08.03.20.45.55
"Default Font"
"Default Font"
0 0 0 0 14 10 0 "Regular 宋体"
PART-TYPE
0 0 0 0 14 10 0 "Regular 宋体"
REF-DES
CLOSED 5 10 255
-100 40
-100 -40
100 -40
100 40
-100 40
T200 0 0 1 50 10 0 4 110 -30 0 0 PIN
P-100 0 0 1 0 0 0 0 128
T-200 0 0 0 50 10 0 4 110 -30 0 0 PIN
P-100 0 0 1 0 0 0 0 128
螺丝孔 0 0 100 10 100 10 2 6 0 1 0 0
TIMESTAMP 2024.08.03.20.45.55
"Default Font"
"Default Font"
0 0 0 0 9 1 0 "Regular default"
PART-TYPE
0 0 0 0 9 1 0 "Regular default"
REF-DES
OPEN 2 10 255
50 80
-50 40
OPEN 2 10 255
50 40
-50 -10
OPEN 2 10 255
50 -10
-50 -60
OPEN 2 10 255
100 80
-100 80
OPEN 5 10 255
50 80
50 -60
0 -110
-50 -60
-50 80
OPEN 2 10 255
-100 80 1431 -1063 -125 -120 125 130
100 80
T0 -120 90 0 10 10 0 4 30 -30 0 0 PIN_2
P-100 0 0 1 0 0 0 0 128
*PARTTYPE*
0603WAF2200T5E UND 1 0 0 0
TIMESTAMP 2024.08.03.20.45.55
GATE 1 2 0
0603WAF2200T5E
2 0 U 2
1 0 U 1
100p UND 1 0 0 0
TIMESTAMP 2024.08.03.20.45.55
GATE 1 2 0
100p
1 0 U 1
2 0 U 2
10114587-001LF UND 1 0 0 0
TIMESTAMP 2024.08.03.20.45.55
GATE 1 60 0
10114587-001LF
P1 0 U P1
P2 0 U P2
P3 0 U P3
P4 0 U P4
P5 0 U P5
P6 0 U P6
P7 0 U P7
P8 0 U P8
P9 0 U P9
P10 0 U P10
P11 0 U P11
P12 0 U P12
P13 0 U P13
P14 0 U P14
P15 0 U P15
P16 0 U P16
P17 0 U P17
P18 0 U P18
P19 0 U P19
P20 0 U P20
P21 0 U P21
P22 0 U P22
P23 0 U P23
P24 0 U P24
P25 0 U P25
P26 0 U P26
P27 0 U P27
P28 0 U P28
P29 0 U P29
P30 0 U P30
P31 0 U P31
P32 0 U P32
P33 0 U P33
P34 0 U P34
P35 0 U P35
P36 0 U P36
S1 0 U S1
S2 0 U S2
S3 0 U S3
S4 0 U S4
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
2.54-1*4P母 UND 1 0 0 0
TIMESTAMP 2024.08.03.20.45.55
GATE 1 4 0
2.54-1*4P母
1 0 U 1
2 0 U 2
3 0 U 3
4 0 U 4
Cap UND 1 0 0 0
TIMESTAMP 2024.08.03.20.45.55
GATE 1 2 0
Cap
1 0 U 1
2 0 U 2
CapAcitance UND 1 0 0 0
TIMESTAMP 2024.08.03.20.45.55
GATE 1 2 0
CapAcitance
1 0 U 1
2 0 U 2
CC0603JRNPO9BN101 UND 1 0 0 0
TIMESTAMP 2024.08.03.20.45.55
GATE 1 2 0
CC0603JRNPO9BN101
1 0 U 1
2 0 U 2
CL21A476MQYNNNE UND 1 0 0 0
TIMESTAMP 2024.08.03.20.45.55
GATE 1 2 0
CL21A476MQYNNNE
1 0 U 1
2 0 U 2
DC-091-A250 UND 1 0 0 0
TIMESTAMP 2024.08.03.20.45.55
GATE 1 3 0
DC-091-A250
3 0 U 3
4 0 U 4
6 0 U 6
ESP32-S3-WROOM-1(N16) UND 1 0 0 0
TIMESTAMP 2024.08.03.20.45.55
GATE 1 41 0
ESP32-S3-WROOM-1(N16)
1 0 U GND
2 0 U 3V3
3 0 U EN
4 0 U IO4
5 0 U IO5
6 0 U IO6
7 0 U IO7
8 0 U IO15
9 0 U IO16
10 0 U IO17
11 0 U IO18
12 0 U IO8
13 0 U IO19
14 0 U IO20
15 0 U IO3
16 0 U IO46
17 0 U IO9
18 0 U IO10
19 0 U IO11
20 0 U IO12
21 0 U IO13
22 0 U IO14
23 0 U IO21
24 0 U IO47
25 0 U IO48
26 0 U IO45
27 0 U IO0
28 0 U IO35
29 0 U IO36
30 0 U IO37
31 0 U IO38
32 0 U IO39
33 0 U IO40
34 0 U IO41
35 0 U IO42
36 0 U RXD0
37 0 U TXD0
38 0 U IO2
39 0 U IO1
40 0 U GND
41 0 U GND
INDUCTOR UND 1 0 0 0
TIMESTAMP 2024.08.03.20.45.55
GATE 1 2 0
INDUCTOR
1 0 U 1
2 0 U 2
MT1470 UND 1 0 0 0
TIMESTAMP 2024.08.03.20.45.55
GATE 1 6 0
MT1470
2 0 U SW
1 0 U GND
4 0 U FB
5 0 U EN
3 0 U VIN
6 0 U BS
NPN UND 1 0 0 0
TIMESTAMP 2024.08.03.20.45.55
GATE 1 3 0
NPN
1 0 U B
3 0 U C
2 0 U E
PZ200V-11-06P UND 1 0 0 0
TIMESTAMP 2024.08.03.20.45.55
GATE 1 6 0
PZ200V-11-06P
GND 0 U GND
BOOT 0 U BOOT
EN 0 U EN
RXD 0 U RXD
TXD 0 U TXD
VCC 0 U VCC
Res2 UND 1 0 0 0
TIMESTAMP 2024.08.03.20.45.55
GATE 1 2 0
Res2
2 0 U 2
1 0 U 1
SMAJ15CA_C1509527 UND 1 0 0 0
TIMESTAMP 2024.08.03.20.45.55
GATE 1 2 0
SMAJ15CA_C1509527
1 0 U 1
2 0 U 2
TS-1088-AR02016 UND 1 0 0 0
TIMESTAMP 2024.08.03.20.45.55
GATE 1 2 0
TS-1088-AR02016
2 0 U 2
1 0 U 1
VC060303A100DP UND 1 0 0 0
TIMESTAMP 2024.08.03.20.45.55
GATE 1 2 0
VC060303A100DP
1 0 U 1
2 0 U 2
XT60 UND 1 0 0 0
TIMESTAMP 2024.08.03.20.45.55
GATE 1 2 0
XT60
1 0 U -
2 0 U +
电阻 UND 1 0 0 0
TIMESTAMP 2024.08.03.20.45.55
GATE 1 2 0
电阻
2 0 U 2
1 0 U 1
螺丝孔 UND 1 0 0 0
TIMESTAMP 2024.08.03.20.45.55
GATE 1 1 0
螺丝孔
1 0 U 1
$PWR_SYMS UND 0 0 2 0
TIMESTAMP 2024.08.03.20.45.55
PWR 4
+12V P +12V
+12VSB P +12VSB
GND P GND
VCC_3V3 P VCC_3V3
$OSR_SYMS UND 0 0 2 0
TIMESTAMP 2024.08.03.20.45.55
OFF 5
CSPS_PROK U
CSPS_PROK_1 U
CSPS_PSON U
CSPS_PSON_1 U
PRESENT U
*PART*
DC1 DC-091-A250 9850 2500 0 0 100 10 100 10 3 29 3 0 0 6
"Default Font"
"Default Font"
-250 150 0 0 139 10 1 "Regular 宋体"
REF-DES
-250 -200 0 0 139 10 1 "Regular 宋体"
PART-TYPE
-250 -200 0 0 139 10 1 "Regular 宋体"
Name
"Name" DC-091-A250
"Symbol" DC-091-A250
"Device" DC-091-A250
"PCB DECAL" DC-IN-TH_DC-091-A250
"Supplier" LCSC
"Supplier Part" C720588
"Manufacturer" XUNPU(讯普)
"Manufacturer Part" DC-091-A250
"JLCPCB Part Class" 扩展库
"LCSC Part Name" DC电源插座 内径:2.5mm 外径:6.45mm
"Supplier Footprint" 插件
"Datasheet" https://atta.szlcsc.com/upload/public/pdf/source/20211022/4405C4A6464D514B1AFE6C16257EC3E0.pdf
"Add into BOM" yes
"Convert to PCB" yes
"3D Model" 71712f683e0d4b868f9bba5c6e495897
"3D Model Title" DC-IN-TH_DC-091-A250
"3D Model Transform" 511.81,393.7,0,0,0,0,-94.488,0,-118.11
"Connector Type" DC电源插座
"Mounting Style" 弯插
"Inside Contact Diameter" 2.5mm
"Outside Contact Diameter" 6.45mm
"Current Rating (Max)" 5A
"Voltage Rating (Max)" 24V
"Operating Temperature Range" -30℃~+70℃
"Description" 连接器类型:DC电源插座;安装方式:弯插;触点内径:2.5mm;触点外径:6.45mm;额定电流:5A;额定电压:24V;工作温度范围:-30℃~+70℃;
"Reuse Block" 
"Group ID" 
"Channel ID" 
"Unique ID" gge1
0 100 10 0 4
1 100 10 0 4
2 100 10 0 4
DC2 DC-091-A250 9850 1950 0 0 100 10 100 10 3 29 3 0 0 6
"Default Font"
"Default Font"
-250 150 0 0 139 10 1 "Regular 宋体"
REF-DES
-250 -200 0 0 139 10 1 "Regular 宋体"
PART-TYPE
-250 -200 0 0 139 10 1 "Regular 宋体"
Name
"Name" DC-091-A250
"Symbol" DC-091-A250
"Device" DC-091-A250
"PCB DECAL" DC-IN-TH_DC-091-A250
"Supplier" LCSC
"Supplier Part" C720588
"Manufacturer" XUNPU(讯普)
"Manufacturer Part" DC-091-A250
"JLCPCB Part Class" 扩展库
"LCSC Part Name" DC电源插座 内径:2.5mm 外径:6.45mm
"Supplier Footprint" 插件
"Datasheet" https://atta.szlcsc.com/upload/public/pdf/source/20211022/4405C4A6464D514B1AFE6C16257EC3E0.pdf
"Add into BOM" yes
"Convert to PCB" yes
"3D Model" 71712f683e0d4b868f9bba5c6e495897
"3D Model Title" DC-IN-TH_DC-091-A250
"3D Model Transform" 511.81,393.7,0,0,0,0,-94.488,0,-118.11
"Connector Type" DC电源插座
"Mounting Style" 弯插
"Inside Contact Diameter" 2.5mm
"Outside Contact Diameter" 6.45mm
"Current Rating (Max)" 5A
"Voltage Rating (Max)" 24V
"Operating Temperature Range" -30℃~+70℃
"Description" 连接器类型:DC电源插座;安装方式:弯插;触点内径:2.5mm;触点外径:6.45mm;额定电流:5A;额定电压:24V;工作温度范围:-30℃~+70℃;
"Reuse Block" 
"Group ID" 
"Channel ID" 
"Unique ID" gge2
0 100 10 0 4
1 100 10 0 4
2 100 10 0 4
DC3 DC-091-A250 9850 1400 0 0 100 10 100 10 3 29 3 0 0 6
"Default Font"
"Default Font"
-250 150 0 0 139 10 1 "Regular 宋体"
REF-DES
-250 -200 0 0 139 10 1 "Regular 宋体"
PART-TYPE
-250 -200 0 0 139 10 1 "Regular 宋体"
Name
"Name" DC-091-A250
"Symbol" DC-091-A250
"Device" DC-091-A250
"PCB DECAL" DC-IN-TH_DC-091-A250
"Supplier" LCSC
"Supplier Part" C720588
"Manufacturer" XUNPU(讯普)
"Manufacturer Part" DC-091-A250
"JLCPCB Part Class" 扩展库
"LCSC Part Name" DC电源插座 内径:2.5mm 外径:6.45mm
"Supplier Footprint" 插件
"Datasheet" https://atta.szlcsc.com/upload/public/pdf/source/20211022/4405C4A6464D514B1AFE6C16257EC3E0.pdf
"Add into BOM" yes
"Convert to PCB" yes
"3D Model" 71712f683e0d4b868f9bba5c6e495897
"3D Model Title" DC-IN-TH_DC-091-A250
"3D Model Transform" 511.81,393.7,0,0,0,0,-94.488,0,-118.11
"Connector Type" DC电源插座
"Mounting Style" 弯插
"Inside Contact Diameter" 2.5mm
"Outside Contact Diameter" 6.45mm
"Current Rating (Max)" 5A
"Voltage Rating (Max)" 24V
"Operating Temperature Range" -30℃~+70℃
"Description" 连接器类型:DC电源插座;安装方式:弯插;触点内径:2.5mm;触点外径:6.45mm;额定电流:5A;额定电压:24V;工作温度范围:-30℃~+70℃;
"Reuse Block" 
"Group ID" 
"Channel ID" 
"Unique ID" gge3
0 100 10 0 4
1 100 10 0 4
2 100 10 0 4
DC4 DC-091-A250 9850 900 0 0 100 10 100 10 3 29 3 0 0 6
"Default Font"
"Default Font"
-250 150 0 0 139 10 1 "Regular 宋体"
REF-DES
-250 -200 0 0 139 10 1 "Regular 宋体"
PART-TYPE
-250 -200 0 0 139 10 1 "Regular 宋体"
Name
"Name" DC-091-A250
"Symbol" DC-091-A250
"Device" DC-091-A250
"PCB DECAL" DC-IN-TH_DC-091-A250
"Supplier" LCSC
"Supplier Part" C720588
"Manufacturer" XUNPU(讯普)
"Manufacturer Part" DC-091-A250
"JLCPCB Part Class" 扩展库
"LCSC Part Name" DC电源插座 内径:2.5mm 外径:6.45mm
"Supplier Footprint" 插件
"Datasheet" https://atta.szlcsc.com/upload/public/pdf/source/20211022/4405C4A6464D514B1AFE6C16257EC3E0.pdf
"Add into BOM" yes
"Convert to PCB" yes
"3D Model" 71712f683e0d4b868f9bba5c6e495897
"3D Model Title" DC-IN-TH_DC-091-A250
"3D Model Transform" 511.81,393.7,0,0,0,0,-94.488,0,-118.11
"Connector Type" DC电源插座
"Mounting Style" 弯插
"Inside Contact Diameter" 2.5mm
"Outside Contact Diameter" 6.45mm
"Current Rating (Max)" 5A
"Voltage Rating (Max)" 24V
"Operating Temperature Range" -30℃~+70℃
"Description" 连接器类型:DC电源插座;安装方式:弯插;触点内径:2.5mm;触点外径:6.45mm;额定电流:5A;额定电压:24V;工作温度范围:-30℃~+70℃;
"Reuse Block" 
"Group ID" 
"Channel ID" 
"Unique ID" gge4
0 100 10 0 4
1 100 10 0 4
2 100 10 0 4
R6 Res2 4250 5600 90 3 100 10 100 10 3 35 2 0 0 30
"Default Font"
"Default Font"
100 0 90 0 139 10 1 "Regular Times New Roman"
REF-DES
200 0 90 0 139 10 1 "Regular Times New Roman"
PART-TYPE
200 0 90 0 139 10 1 "Regular Times New Roman"
Name
"Name" 100kΩ
"Symbol" Res2
"Device" RC0603FR-071KL
"PCB DECAL" R0603
"LCSC Part Name" 1kΩ ±1% 100mW
"Supplier Part" 
"Manufacturer" YAGEO(国巨)
"Manufacturer Part" RC0603FR-071KL
"Supplier Footprint" 0603
"JLCPCB Part Class" Extended Part
"Datasheet" https://atta.szlcsc.com/upload/public/pdf/source/20180312/7BD3618A8B6324EA6280B0497A051AB7.pdf
"Supplier" LCSC
"Add into BOM" yes
"Convert to PCB" yes
"3D Model" fc143cca1e79419f9cd78b61e9279f08
"3D Model Title" R0603
"3D Model Transform" 31.8897,63.7794,0,90,0,0,0,0,0
"Type" 厚膜电阻
"Value" 100kΩ
"Tolerance" ±1%
"Power(Watts)" 100mW
"Temperature Coefficient" ±100ppm/℃
"Overload Voltage (Max)" 75V
"Operating Temperature Range" -55℃~+155℃
"Description" 电阻类型:厚膜电阻;阻值:1kΩ;精度:±1%;功率:100mW;
"Origin Footprint 1" 0603R
"Unique ID" ba2c6d155e7fd301
"Design Item ID" Res2
"Library Name" Miscellaneous Devices
"Origin Footprint 2" AXIAL-0.4
"Origin Footprint 3" R0402
"Origin Footprint 4" 0402
"Reuse Block" 
"Group ID" 
"Channel ID" 
0 50 10 0 4
1 50 10 0 4
Q1 NPN 5150 4250 0 1 100 10 100 10 3 29 3 0 0 30
"Default Font"
"Default Font"
400 200 0 1 139 10 1 "Regular Times New Roman"
REF-DES
400 -700 0 1 139 10 1 "Regular Times New Roman"
PART-TYPE
400 -700 0 1 139 10 1 "Regular Times New Roman"
Name
"Name" DTC143ZCA
"Symbol" NPN
"Device" DTC143ZCA_C15236
"PCB DECAL" SOT-23-3_L2.9-W1.3-P1.90-LS2.4-BR
"LCSC Part Name" 电流:100mA 耐压:50V
"Supplier Part" C15236
"Manufacturer" CJ(江苏长电/长晶)
"Manufacturer Part" DTC143ZCA
"Supplier Footprint" SOT-23
"JLCPCB Part Class" Extended Part
"Datasheet" https://atta.szlcsc.com/upload/public/pdf/source/20140809/1457707205046.pdf
"Supplier" LCSC
"Add into BOM" yes
"Convert to PCB" yes
"3D Model" c62791f0466c4ae2a892c056b845b0ca
"3D Model Title" SOT-23-3P_L2.9-W1.3-H1.0-LS2.4-P0.95
"3D Model Transform" 98.425,114.173,0,180,0,0,0.0005,-0.0005,0
"Power Dissipation (Pd)" 200mW
"Collector-Emitter Breakdown Voltage (Vceo)" 50V
"Transistor Type" 1个NPN-预偏置
"Collector Current (Ic)" 100mA
"Description" 功率(Pd):200mW;集射极击穿电压(Vceo):50V;晶体管类型:1个NPN-预偏置;集电极电流(Ic):100mA;
"Origin Footprint" SOT23
"Unique ID" f76c01de5337d462
"Design Item ID" NPN
"Library Name" U_PP SCH
"Reuse Block" 
"Group ID" 
"Channel ID" 
0 100 10 0 4
1 100 10 0 4
2 100 10 0 4
U3 MT1470 5200 1650 0 0 100 10 100 10 3 33 6 0 0 6
"Default Font"
"Default Font"
-250 -300 0 0 139 10 1 "Regular Times New Roman"
REF-DES
-250 -400 0 0 139 10 1 "Regular Times New Roman"
PART-TYPE
-250 -400 0 0 139 10 1 "Regular Times New Roman"
Name
"Name" MT1470
"Symbol" MT1470
"Device" MT1470
"PCB DECAL" SOT-23-6_L2.9-W1.6-P0.95-LS2.8-BR
"LCSC Part Name" 停产
"Supplier Part" C181781
"Manufacturer" 西安航天民芯
"Manufacturer Part" MT1470
"Supplier Footprint" SOT-23-6
"JLCPCB Part Class" Extended Part
"Datasheet" https://atta.szlcsc.com/upload/public/pdf/source/20210917/0B5B51B60596D99E36E81A9EF9D9BC0F.pdf
"Supplier" LCSC
"Add into BOM" yes
"Convert to PCB" yes
"3D Model" 18da8f6c14a34920b3e136b5c401a119
"3D Model Title" SOT-23-6_L2.9-W1.6-H1.5-LS2.8-P0.95
"3D Model Transform" 110.73671,114.173,0,180,0,0,0.001,-0.003,0
"Function" 降压型
"Input Voltage" -
"Output Current (Max)" -
"Switching Frequency" -
"Synchronous Rectification" -
"Number of Outputs" -
"Topology" -
"Switch tube (built-in/external)" 内置
"Description" 功能类型:降压型;输入电压:-;输出电流(最大值):-;
"Origin Footprint" SOT23-6
"Unique ID" 1bdc0ab44f99f92d
"Design Item ID" MT1470
"Library Name" U_PP SCH
"Reuse Block" 
"Group ID" 
"Channel ID" 
0 50 10 0 4
1 50 10 0 4
2 50 10 0 4
3 50 10 0 4
4 50 10 0 4
5 50 10 0 4
C5 Cap 4275 1500 90 3 100 10 100 10 3 29 2 0 0 30
"Default Font"
"Default Font"
100 -450 90 0 139 10 1 "Regular Times New Roman"
REF-DES
200 -500 90 0 139 10 1 "Regular Times New Roman"
PART-TYPE
200 -500 90 0 139 10 1 "Regular Times New Roman"
Name
"Name" 10uF
"Symbol" Cap
"Device" CL21A106KAYNNNE_C15850
"PCB DECAL" C0805
"LCSC Part Name" 10uF ±10% 25V
"Supplier Part" C15850
"Manufacturer" SAMSUNG(三星)
"Manufacturer Part" CL21A106KAYNNNE
"Supplier Footprint" 0805
"JLCPCB Part Class" Basic Part
"Datasheet" https://atta.szlcsc.com/upload/public/pdf/source/20160103/1457707679302.pdf
"Supplier" LCSC
"Add into BOM" yes
"Convert to PCB" yes
"3D Model" 1ba041120af144c991958decab20d241
"3D Model Title" C0805_L2.0-W1.3-H1.3
"3D Model Transform" 78.74,51.181,0,0,0,0,0,0.0005,0
"Value" 10uF
"Tolerance" ±10%
"Voltage Rated" 25V
"Temperature Coefficient" X5R
"Description" 容值:10uF;精度:±10%;额定电压:25V;材质(温度系数):X5R;
"Origin Footprint" 1206C
"Unique ID" b4693cfd16d534cd
"Design Item ID" Cap
"Library Name" Miscellaneous Devices
"Reuse Block" 
"Group ID" 
"Channel ID" 
0 50 10 0 4
1 50 10 0 4
R7 Res2 3875 1550 0 3 100 10 100 10 3 34 2 0 0 30
"Default Font"
"Default Font"
100 -250 0 3 139 10 1 "Regular Times New Roman"
REF-DES
100 -150 0 3 139 10 1 "Regular Times New Roman"
PART-TYPE
100 -150 0 3 139 10 1 "Regular Times New Roman"
Name
"Name" 0Ω
"Symbol" Res2
"Device" 0603WAF0000T5E
"PCB DECAL" R0603
"LCSC Part Name" 0Ω ±1% 100mW 厚膜电阻
"Supplier Part" C21189
"Manufacturer" UNI-ROYAL(厚声)
"Manufacturer Part" 0603WAF0000T5E
"Supplier Footprint" 0603
"JLCPCB Part Class" Basic Part
"Datasheet" https://atta.szlcsc.com/upload/public/pdf/source/20200306/C422600_1E6D84923E4A46A82E41ADD87F860B5C.pdf
"Supplier" LCSC
"Add into BOM" yes
"Convert to PCB" yes
"3D Model" fc143cca1e79419f9cd78b61e9279f08
"3D Model Title" R0603
"3D Model Transform" 31.8897,63.7794,0,90,0,0,0,0,0
"Value" 0Ω
"Tolerance" ±1%
"Power(Watts)" 100mW
"Overload Voltage (Max)" 75V
"Type" 厚膜电阻
"Operating Temperature Range" -55℃~+155℃
"Description" 阻值:0Ω;精度:±1%;功率:100mW;电阻类型:厚膜电阻;
"Origin Footprint 1" 0603R
"Unique ID" 353b166cc2dee846
"Design Item ID" Res2
"Library Name" Miscellaneous Devices
"Origin Footprint 2" AXIAL-0.4
"Origin Footprint 3" R0402
"Origin Footprint 4" 0402
"Reuse Block" 
"Group ID" 
"Channel ID" 
0 50 10 0 4
1 50 10 0 4
R9 Res2 4325 1350 90 0 100 10 100 10 3 34 2 0 0 30
"Default Font"
"Default Font"
100 -140 90 3 139 10 1 "Regular Times New Roman"
REF-DES
0 -140 90 3 139 10 1 "Regular Times New Roman"
PART-TYPE
0 -140 90 3 139 10 1 "Regular Times New Roman"
Name
"Name" 100kΩ
"Symbol" Res2
"Device" RC0603FR-07100KL
"PCB DECAL" R0603
"LCSC Part Name" 厚膜电阻 100kΩ ±1% 100mW
"Supplier Part" C14675
"Manufacturer" YAGEO(国巨)
"Manufacturer Part" RC0603FR-07100KL
"Supplier Footprint" 0603
"JLCPCB Part Class" Extended Part
"Datasheet" https://atta.szlcsc.com/upload/public/pdf/source/20140324/1457707028752.pdf
"Supplier" LCSC
"Add into BOM" yes
"Convert to PCB" yes
"3D Model" fc143cca1e79419f9cd78b61e9279f08
"3D Model Title" R0603
"3D Model Transform" 31.8897,63.7794,0,90,0,0,0,0,0
"Type" 厚膜电阻
"Value" 100kΩ
"Tolerance" ±1%
"Power(Watts)" 100mW
"Temperature Coefficient" ±100ppm/℃
"Overload Voltage (Max)" 75V
"Operating Temperature Range" -55℃~+155℃
"Description" 电阻类型:厚膜电阻;阻值:100kΩ;精度:±1%;功率:100mW;温度系数:±100ppm/℃;
"Origin Footprint 1" 0603R
"Unique ID" 6f63fc6711cfa315
"Design Item ID" Res2
"Library Name" Miscellaneous Devices
"Origin Footprint 2" AXIAL-0.4
"Origin Footprint 3" R0402
"Reuse Block" 
"Group ID" 
"Channel ID" 
0 50 10 0 4
1 50 10 0 4
R8 Res2 6100 1450 90 0 100 10 100 10 3 34 2 0 0 30
"Default Font"
"Default Font"
100 -140 90 3 139 10 1 "Regular Times New Roman"
REF-DES
0 -140 90 3 139 10 1 "Regular Times New Roman"
PART-TYPE
0 -140 90 3 139 10 1 "Regular Times New Roman"
Name
"Name" 100kΩ
"Symbol" Res2
"Device" RC0603FR-07100KL
"PCB DECAL" R0603
"LCSC Part Name" 厚膜电阻 100kΩ ±1% 100mW
"Supplier Part" C14675
"Manufacturer" YAGEO(国巨)
"Manufacturer Part" RC0603FR-07100KL
"Supplier Footprint" 0603
"JLCPCB Part Class" Extended Part
"Datasheet" https://atta.szlcsc.com/upload/public/pdf/source/20140324/1457707028752.pdf
"Supplier" LCSC
"Add into BOM" yes
"Convert to PCB" yes
"3D Model" fc143cca1e79419f9cd78b61e9279f08
"3D Model Title" R0603
"3D Model Transform" 31.8897,63.7794,0,90,0,0,0,0,0
"Type" 厚膜电阻
"Value" 100kΩ
"Tolerance" ±1%
"Power(Watts)" 100mW
"Temperature Coefficient" ±100ppm/℃
"Overload Voltage (Max)" 75V
"Operating Temperature Range" -55℃~+155℃
"Description" 电阻类型:厚膜电阻;阻值:100kΩ;精度:±1%;功率:100mW;温度系数:±100ppm/℃;
"Origin Footprint 1" 0603R
"Unique ID" fe89d0632cfce75f
"Design Item ID" Res2
"Library Name" Miscellaneous Devices
"Origin Footprint 2" AXIAL-0.4
"Origin Footprint 3" R0402
"Reuse Block" 
"Group ID" 
"Channel ID" 
0 50 10 0 4
1 50 10 0 4
R10 Res2 6100 1050 90 0 100 10 100 10 3 34 2 0 0 30
"Default Font"
"Default Font"
100 -140 90 3 139 10 1 "Regular Times New Roman"
REF-DES
0 -140 90 3 139 10 1 "Regular Times New Roman"
PART-TYPE
0 -140 90 3 139 10 1 "Regular Times New Roman"
Name
"Name" 31.6kΩ
"Symbol" Res2
"Device" 0603WAF3162T5E
"PCB DECAL" R0603
"LCSC Part Name" 31.6kΩ ±1% 100mW 厚膜电阻
"Supplier Part" C25967
"Manufacturer" UNI-ROYAL(厚声)
"Manufacturer Part" 0603WAF3162T5E
"Supplier Footprint" 0603
"JLCPCB Part Class" Extended Part
"Datasheet" https://atta.szlcsc.com/upload/public/pdf/source/20200306/C422600_1E6D84923E4A46A82E41ADD87F860B5C.pdf
"Supplier" LCSC
"Add into BOM" yes
"Convert to PCB" yes
"3D Model" fc143cca1e79419f9cd78b61e9279f08
"3D Model Title" R0603
"3D Model Transform" 31.8897,63.7794,0,90,0,0,0,0,0
"Value" 31.6kΩ
"Tolerance" ±1%
"Power(Watts)" 100mW
"Overload Voltage (Max)" 75V
"Temperature Coefficient" ±100ppm/℃
"Type" 厚膜电阻
"Operating Temperature Range" -55℃~+155℃
"Description" 阻值:31.6kΩ;精度:±1%;功率:100mW;温度系数:±100ppm/℃;电阻类型:厚膜电阻;
"Origin Footprint 1" 0603R
"Unique ID" fdc86a4b576d9e98
"Design Item ID" Res2
"Library Name" Miscellaneous Devices
"Origin Footprint 2" AXIAL-0.4
"Origin Footprint 3" R0402
"Reuse Block" 
"Group ID" 
"Channel ID" 
0 50 10 0 4
1 50 10 0 4
C6 Cap 6900 1550 90 0 100 10 100 10 3 30 2 0 0 30
"Default Font"
"Default Font"
10 -190 90 3 139 10 1 "Regular Times New Roman"
REF-DES
-90 -190 90 3 139 10 1 "Regular Times New Roman"
PART-TYPE
-90 -190 90 3 139 10 1 "Regular Times New Roman"
Name
"Name" 100nF
"Symbol" Cap
"Device" 0603B104K500NT
"PCB DECAL" C0603
"LCSC Part Name" 100nF ±10% 50V
"Supplier Part" C30926
"Manufacturer" FH(风华)
"Manufacturer Part" 0603B104K500NT
"Supplier Footprint" 0603
"JLCPCB Part Class" Extended Part
"Datasheet" https://atta.szlcsc.com/upload/public/pdf/source/20200305/C486355_26A10D38EF8C2A5C37091D0039909270.pdf
"Supplier" LCSC
"Add into BOM" yes
"Convert to PCB" yes
"3D Model" ac125912035d415993ca9572d50418b1
"3D Model Title" C0603_L1.6-W0.8-H0.8
"3D Model Transform" 62.992,31.496,0,0,0,0,0,0,0
"Value" 100nF
"Tolerance" ±10%
"Voltage Rated" 50V
"Temperature Coefficient" X7R
"Description" 容值:100nF;精度:±10%;额定电压:50V;材质(温度系数):X7R;
"Origin Footprint 1" 0603C
"Unique ID" 3a68d3ddabf48558
"Design Item ID" Cap
"Library Name" Miscellaneous Devices
"Origin Footprint 2" 0402
"Reuse Block" 
"Group ID" 
"Channel ID" 
0 50 10 0 4
1 50 10 0 4
L1 INDUCTOR 5775 1650 90 0 100 10 100 10 3 32 2 0 0 30
"Default Font"
"Default Font"
250 0 90 3 139 10 1 "Regular Times New Roman"
REF-DES
150 0 90 3 139 10 1 "Regular Times New Roman"
PART-TYPE
150 0 90 3 139 10 1 "Regular Times New Roman"
Name
"Name" 4.7uH
"Symbol" INDUCTOR
"Device" SWPA3015S4R7MT
"PCB DECAL" IND-SMD_L3.0-W3.0_FNR30XXS
"LCSC Part Name" 4.7uH ±20% 1.4A
"Supplier Part" C19398
"Manufacturer" Sunlord(顺络)
"Manufacturer Part" SWPA3015S4R7MT
"Supplier Footprint" SMD
"JLCPCB Part Class" Extended Part
"Datasheet" https://atta.szlcsc.com/upload/public/pdf/source/20210916/AC798BA7E846B7D0B6818F45CD84DB0B.pdf
"Supplier" LCSC
"Add into BOM" yes
"Convert to PCB" yes
"3D Model" 822d71758aa744dca2559abd61137eb2
"3D Model Title" IND-SMD_L3.0-W3.0-H1.5_FNR30XXS
"3D Model Transform" 118.11,118.11,0,90,0,0,0,0,0
"Type" -
"Value" 4.7uH
"Tolerance" ±20%
"Rated Current" 1.09A
"Saturation Current (Isat)" 1.4A
"DC Resistance (DCR)" 163mΩ
"Ratings" -
"Description" 类型:-;电感值:4.7uH;精度:±20%;额定电流:1.09A;饱和电流(Isat):1.4A;
"Origin Footprint" COKE_3X3A
"Unique ID" d450ceac7adb81c3
"Design Item ID" INDUCTOR
"Library Name" U_PP SCH
"Reuse Block" 
"Group ID" 
"Channel ID" 
0 50 10 0 4
1 50 10 0 4
C3 Cap 5150 2100 0 0 100 10 100 10 3 30 2 0 0 30
"Default Font"
"Default Font"
-125 50 0 0 139 10 1 "Regular Times New Roman"
REF-DES
75 50 0 0 139 10 1 "Regular Times New Roman"
PART-TYPE
75 50 0 0 139 10 1 "Regular Times New Roman"
Name
"Name" 100nF
"Symbol" Cap
"Device" 0603B104K500NT
"PCB DECAL" C0603
"LCSC Part Name" 100nF ±10% 50V
"Supplier Part" C30926
"Manufacturer" FH(风华)
"Manufacturer Part" 0603B104K500NT
"Supplier Footprint" 0603
"JLCPCB Part Class" Extended Part
"Datasheet" https://atta.szlcsc.com/upload/public/pdf/source/20200305/C486355_26A10D38EF8C2A5C37091D0039909270.pdf
"Supplier" LCSC
"Add into BOM" yes
"Convert to PCB" yes
"3D Model" ac125912035d415993ca9572d50418b1
"3D Model Title" C0603_L1.6-W0.8-H0.8
"3D Model Transform" 62.992,31.496,0,0,0,0,0,0,0
"Value" 100nF
"Tolerance" ±10%
"Voltage Rated" 50V
"Temperature Coefficient" X7R
"Description" 容值:100nF;精度:±10%;额定电压:50V;材质(温度系数):X7R;
"Origin Footprint 1" 0603C
"Unique ID" a2c5d49bc5dde298
"Design Item ID" Cap
"Library Name" Miscellaneous Devices
"Origin Footprint 2" 0402
"Reuse Block" 
"Group ID" 
"Channel ID" 
0 50 10 0 4
1 50 10 0 4
U2 ESP32-S3-WROOM-1(N16) 8850 5550 0 0 100 10 100 10 3 25 41 0 0 6
"Default Font"
"Default Font"
1050 1000 0 0 97 10 1 "Regular default"
REF-DES
-450 800 0 0 139 10 1 "Regular 宋体"
PART-TYPE
-450 800 0 0 139 10 1 "Regular 宋体"
Name
"Name" ESP32-S3-WROOM-1-N16
"Symbol" ESP32-S3-WROOM-1(N16)
"Device" ESP32-S3-WROOM-1-N16
"PCB DECAL" WIRELM-SMD_ESP32-S3-WROOM-1
"LCSC Part Name" 通用型Wi-Fi+低功耗蓝牙MCU模组
"Supplier Part" C2913199
"Manufacturer" ESPRESSIF(乐鑫)
"Manufacturer Part" ESP32-S3-WROOM-1-N16
"Supplier Footprint" SMD,18x25.5mm
"JLCPCB Part Class" Extended Part
"Datasheet" https://atta.szlcsc.com/upload/public/pdf/source/20220628/A2AC12B3C87735CAEB7EBE2DBE80936C.pdf
"Supplier" LCSC
"Add into BOM" yes
"Convert to PCB" yes
"3D Model" 481f5bdfc076422c9bb3c23c3ada9c17
"3D Model Title" WIRELM-SMD_ESP32-S3-WROOM-1
"3D Model Transform" 708.73866,1003.97437,0,0,0,0,0,143.7,0
"Description" 
"Origin Footprint" WIRELM-SMD_ESP32-S3-WROOM-1
"Unique ID" 124c013cfc851acc
"Design Item ID" ESP32-S3-WROOM-1(N16)
"Designer" U?
"Reuse Block" 
"Group ID" 
"Channel ID" 
0 50 10 0 4
1 50 10 0 4
2 50 10 0 4
3 50 10 0 4
4 50 10 0 4
5 50 10 0 4
6 50 10 0 4
7 50 10 0 4
8 50 10 0 4
9 50 10 0 4
10 50 10 0 4
11 50 10 0 4
12 50 10 0 4
13 50 10 0 4
14 50 10 0 4
15 50 10 0 4
16 50 10 0 4
17 50 10 0 4
18 50 10 0 4
19 50 10 0 4
20 50 10 0 4
21 50 10 0 4
22 50 10 0 4
23 50 10 0 4
24 50 10 0 4
25 50 10 0 4
26 50 10 0 4
27 50 10 0 4
28 50 10 0 4
29 50 10 0 4
30 50 10 0 4
31 50 10 0 4
32 50 10 0 4
33 50 10 0 4
34 50 10 0 4
35 50 10 0 4
36 50 10 0 4
37 50 10 0 4
38 50 10 0 4
39 50 10 0 4
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
"Default Font"
"Default Font"
46 100 90 0 139 10 1 "Regular 宋体"
REF-DES
136 100 90 0 139 10 1 "Regular 宋体"
PART-TYPE
136 100 90 0 139 10 1 "Regular 宋体"
Name
"Name" 100pF
"Symbol" 100p
"Device" CC0603JRNPO9BN101
"PCB DECAL" C0603
"LCSC Part Name" 100pF ±5% 50V
"Supplier Part" C14665
"Manufacturer" YAGEO(国巨)
"Manufacturer Part" CC0603JRNPO9BN101
"Supplier Footprint" 0603
"JLCPCB Part Class" Extended Part
"Datasheet" https://atta.szlcsc.com/upload/public/pdf/source/20181008/C309499_21CC21451B82C39E3D92150FD6B30293.pdf
"Supplier" LCSC
"Add into BOM" yes
"Convert to PCB" yes
"3D Model" ac125912035d415993ca9572d50418b1
"3D Model Title" C0603_L1.6-W0.8-H0.8
"3D Model Transform" 62.992,31.496,0,0,0,0,0,0,0
"Value" 100pF
"Tolerance" ±5%
"Voltage Rated" 50V
"Temperature Coefficient" NP0
"Description" 容值:100pF;精度:±5%;额定电压:50V;材质(温度系数):NP0;
"Origin Footprint" C1206
"Unique ID" gge6
"Reuse Block" 
"Group ID" 
"Channel ID" 
0 50 10 0 4
1 50 10 0 4
R4 电阻 5650 6300 90 0 100 10 100 10 3 29 2 0 0 30
"Default Font"
"Default Font"
0 -100 90 3 139 10 1 "Regular 宋体"
REF-DES
-100 -100 90 3 139 10 1 "Regular 宋体"
PART-TYPE
-100 -100 90 3 139 10 1 "Regular 宋体"
Name
"Name" 3kΩ
"Symbol" 电阻
"Device" RC0603FR-073KL
"PCB DECAL" R0603
"LCSC Part Name" 厚膜电阻 3kΩ ±1% 100mW
"Supplier Part" C126358
"Manufacturer" YAGEO(国巨)
"Manufacturer Part" RC0603FR-073KL
"Supplier Footprint" 0603
"JLCPCB Part Class" Extended Part
"Datasheet" https://atta.szlcsc.com/upload/public/pdf/source/20170914/C127450_1505359406912967677.pdf
"Supplier" LCSC
"Add into BOM" yes
"Convert to PCB" yes
"3D Model" fc143cca1e79419f9cd78b61e9279f08
"3D Model Title" R0603
"3D Model Transform" 31.8897,63.7794,0,90,0,0,0,0,0
"Type" 厚膜电阻
"Value" 3kΩ
"Tolerance" ±1%
"Power(Watts)" 100mW
"Overload Voltage (Max)" 75V
"Temperature Coefficient" ±100ppm/℃
"Operating Temperature Range" -55℃~+155℃
"Description" 电阻类型:厚膜电阻;阻值:3kΩ;精度:±1%;功率:100mW;最大工作电压:75V;温度系数:±100ppm/℃;
"Reuse Block" 
"Group ID" 
"Channel ID" 
"Unique ID" gge7
0 50 10 0 4
1 50 10 0 4
R1 电阻 5650 6800 90 0 100 10 100 10 3 29 2 0 0 30
"Default Font"
"Default Font"
0 -100 90 3 139 10 1 "Regular 宋体"
REF-DES
-100 -100 90 3 139 10 1 "Regular 宋体"
PART-TYPE
-100 -100 90 3 139 10 1 "Regular 宋体"
Name
"Name" 8.2kΩ
"Symbol" 电阻
"Device" RC0603FR-078K2L
"PCB DECAL" R0603
"LCSC Part Name" 8.2kΩ ±1% 100mW
"Supplier Part" C114637
"Manufacturer" YAGEO(国巨)
"Manufacturer Part" RC0603FR-078K2L
"Supplier Footprint" 0603
"JLCPCB Part Class" Extended Part
"Datasheet" https://atta.szlcsc.com/upload/public/pdf/source/20170912/C114637_1505207799594963452.pdf
"Supplier" LCSC
"Add into BOM" yes
"Convert to PCB" yes
"3D Model" fc143cca1e79419f9cd78b61e9279f08
"3D Model Title" R0603
"3D Model Transform" 31.8897,63.7794,0,90,0,0,0,0,0
"Type" 厚膜电阻
"Value" 8.2kΩ
"Tolerance" ±1%
"Power(Watts)" 100mW
"Temperature Coefficient" ±100ppm/℃
"Overload Voltage (Max)" 75V
"Operating Temperature Range" -55℃~+155℃
"Description" 电阻类型:厚膜电阻;阻值:8.2kΩ;精度:±1%;功率:100mW;
"Reuse Block" 
"Group ID" 
"Channel ID" 
"Unique ID" gge8
0 50 10 0 4
1 50 10 0 4
SCREW1 螺丝孔 1000 1420 0 0 100 10 100 10 3 12 1 0 0 30
"Default Font"
"Default Font"
150 150 0 0 139 10 1 "Regular 宋体"
REF-DES
-1000 -1420 0 0 139 10 1 "Regular 宋体"
PART-TYPE
-1000 -1420 0 0 139 10 1 "Regular 宋体"
Name
"Name" 
"Symbol" 螺丝孔
"Device" M3螺丝
"PCB DECAL" M3螺丝
"Convert to PCB" yes
"Add into BOM" yes
"Supplier Footprint" 插件
"Description" 
"Reuse Block" 
"Group ID" 
"Channel ID" 
"Unique ID" gge9
0 10 10 0 4
SCREW2 螺丝孔 2100 1420 0 0 100 10 100 10 3 12 1 0 0 30
"Default Font"
"Default Font"
150 150 0 0 139 10 1 "Regular 宋体"
REF-DES
-2100 -1420 0 0 139 10 1 "Regular 宋体"
PART-TYPE
-2100 -1420 0 0 139 10 1 "Regular 宋体"
Name
"Name" 
"Symbol" 螺丝孔
"Device" M3螺丝
"PCB DECAL" M3螺丝
"Convert to PCB" yes
"Add into BOM" yes
"Supplier Footprint" 插件
"Description" 
"Reuse Block" 
"Group ID" 
"Channel ID" 
"Unique ID" gge10
0 10 10 0 4
SCREW3 螺丝孔 1000 920 0 0 100 10 100 10 3 12 1 0 0 30
"Default Font"
"Default Font"
150 150 0 0 139 10 1 "Regular 宋体"
REF-DES
-1000 -920 0 0 139 10 1 "Regular 宋体"
PART-TYPE
-1000 -920 0 0 139 10 1 "Regular 宋体"
Name
"Name" 
"Symbol" 螺丝孔
"Device" M3螺丝
"PCB DECAL" M3螺丝
"Convert to PCB" yes
"Add into BOM" yes
"Supplier Footprint" 插件
"Description" 
"Reuse Block" 
"Group ID" 
"Channel ID" 
"Unique ID" gge11
0 10 10 0 4
SCREW4 螺丝孔 2100 920 0 0 100 10 100 10 3 12 1 0 0 30
"Default Font"
"Default Font"
150 150 0 0 139 10 1 "Regular 宋体"
REF-DES
-2100 -920 0 0 139 10 1 "Regular 宋体"
PART-TYPE
-2100 -920 0 0 139 10 1 "Regular 宋体"
Name
"Name" 
"Symbol" 螺丝孔
"Device" M3螺丝
"PCB DECAL" M3螺丝
"Convert to PCB" yes
"Add into BOM" yes
"Supplier Footprint" 插件
"Description" 
"Reuse Block" 
"Group ID" 
"Channel ID" 
"Unique ID" gge12
0 10 10 0 4
U1 10114587-001LF 1700 5200 0 0 100 10 100 10 3 14 60 0 0 6
"Default Font"
"Default Font"
-200 1600 0 0 139 10 1 "Regular 宋体"
REF-DES
-1700 -5200 0 0 139 10 1 "Regular 宋体"
PART-TYPE
-1700 -5200 0 0 139 10 1 "Regular 宋体"
Name
"Name" 
"Symbol" 10114587-001LF
"Device" 10114587-001LF
"PCB DECAL" 10114587-001LF
"Add into BOM" yes
"Convert to PCB" yes
"3D Model" fefd7d9ffc714e33bee46679fa77a5c6
"3D Model Title" 10114587-001LF
"3D Model Transform" 2759.01,767.3100000000001,285.43,0,90,0,0,141.73,232.28
"Description" DELL电源金手指连接器36P24S 立式
"Reuse Block" 
"Group ID" 
"Channel ID" 
"Unique ID" gge5
0 100 10 0 4
1 100 10 0 4
2 100 10 0 4
3 100 10 0 4
4 100 10 0 4
5 100 10 0 4
6 100 10 0 4
7 100 10 0 4
8 100 10 0 4
9 100 10 0 4
10 100 10 0 4
11 100 10 0 4
12 100 10 0 4
13 100 10 0 4
14 100 10 0 4
15 100 10 0 4
16 100 10 0 4
17 100 10 0 4
18 100 10 0 4
19 100 10 0 4
20 100 10 0 4
21 100 10 0 4
22 100 10 0 4
23 100 10 0 4
24 100 10 0 4
25 100 10 0 4
26 100 10 0 4
27 100 10 0 4
28 100 10 0 4
29 100 10 0 4
30 100 10 0 4
31 100 10 0 4
32 100 10 0 4
33 100 10 0 4
34 100 10 0 4
35 100 10 0 4
36 100 10 0 4
37 100 10 0 4
38 100 10 0 4
39 100 10 0 4
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
U4 XT60 7850 2600 0 3 100 10 100 10 3 46 2 0 0 6
"Default Font"
"Default Font"
100 -150 0 3 125 10 1 "Regular Arial"
REF-DES
100 250 0 3 125 10 1 "Regular Arial"
PART-TYPE
100 250 0 3 125 10 1 "Regular Arial"
Name
"Name" XT60
"Symbol" XT60
"Device" XT60
"PCB DECAL" CONN-TH_XT60
"LCSC Part Name" AMASS(艾迈斯) XT60模型插头 3.5mm镀金香蕉头公头（电调端）XT60-M
"Supplier Part" C98733
"Manufacturer" AMASS(艾迈斯)
"Manufacturer Part" XT60
"Supplier Footprint" -
"JLCPCB Part Class" Extended Part
"Datasheet" https://atta.szlcsc.com/upload/public/pdf/source/20170606/1496716524919.pdf
"Supplier" LCSC
"Add into BOM" yes
"Convert to PCB" yes
"3D Model" 185081e4ebbe4eaea4bbf508888b62e2
"3D Model Title" CONN-TH_XT60
"3D Model Transform" 610.235,319.291,0,0,0,0,0,0,-196.85
"Description" 模型锂电连接器 XT60-M
"Brand" 艾迈斯
"Model" XT60PW-M
"Power" -
"Output" -
"Input" -
"Size" -
"Interface" -
"Type" 卧式插头
"Colour" 黄色
"MaximumCurrent" -
"RatedVoltage" -
"Type1" -
"NumberOfUSBHoles" -
"InterfaceType" 公头
"MetalMaterial" -
"InsulationMaterial" -
"RatedCurrent" -
"RecommendedWireGauge" -
"FlameRetardantGrade" -
"contact resistance" -
"Belt length" -
"specifications" -
"Origin Footprint" TH_2P-XT60PW-F
"Unique ID" 66797bcd97f4f6c2
"Design Item ID" XT60PW-F
"Reuse Block" 
"Group ID" 
"Channel ID" 
0 50 10 0 4
1 50 10 0 4
U5 XT60 7850 2050 0 3 100 10 100 10 3 46 2 0 0 6
"Default Font"
"Default Font"
100 -150 0 3 125 10 1 "Regular Arial"
REF-DES
100 250 0 3 125 10 1 "Regular Arial"
PART-TYPE
100 250 0 3 125 10 1 "Regular Arial"
Name
"Name" XT60
"Symbol" XT60
"Device" XT60
"PCB DECAL" CONN-TH_XT60
"LCSC Part Name" AMASS(艾迈斯) XT60模型插头 3.5mm镀金香蕉头公头（电调端）XT60-M
"Supplier Part" C98733
"Manufacturer" AMASS(艾迈斯)
"Manufacturer Part" XT60
"Supplier Footprint" -
"JLCPCB Part Class" Extended Part
"Datasheet" https://atta.szlcsc.com/upload/public/pdf/source/20170606/1496716524919.pdf
"Supplier" LCSC
"Add into BOM" yes
"Convert to PCB" yes
"3D Model" 185081e4ebbe4eaea4bbf508888b62e2
"3D Model Title" CONN-TH_XT60
"3D Model Transform" 610.235,319.291,0,0,0,0,0,0,-196.85
"Description" 模型锂电连接器 XT60-M
"Brand" 艾迈斯
"Model" XT60PW-M
"Power" -
"Output" -
"Input" -
"Size" -
"Interface" -
"Type" 卧式插头
"Colour" 黄色
"MaximumCurrent" -
"RatedVoltage" -
"Type1" -
"NumberOfUSBHoles" -
"InterfaceType" 公头
"MetalMaterial" -
"InsulationMaterial" -
"RatedCurrent" -
"RecommendedWireGauge" -
"FlameRetardantGrade" -
"contact resistance" -
"Belt length" -
"specifications" -
"Origin Footprint" TH_2P-XT60PW-F
"Unique ID" gge13
"Design Item ID" XT60PW-F
"Reuse Block" 
"Group ID" 
"Channel ID" 
0 50 10 0 4
1 50 10 0 4
U6 XT60 7850 1500 0 3 100 10 100 10 3 46 2 0 0 6
"Default Font"
"Default Font"
100 -150 0 3 125 10 1 "Regular Arial"
REF-DES
100 250 0 3 125 10 1 "Regular Arial"
PART-TYPE
100 250 0 3 125 10 1 "Regular Arial"
Name
"Name" XT60
"Symbol" XT60
"Device" XT60
"PCB DECAL" CONN-TH_XT60
"LCSC Part Name" AMASS(艾迈斯) XT60模型插头 3.5mm镀金香蕉头公头（电调端）XT60-M
"Supplier Part" C98733
"Manufacturer" AMASS(艾迈斯)
"Manufacturer Part" XT60
"Supplier Footprint" -
"JLCPCB Part Class" Extended Part
"Datasheet" https://atta.szlcsc.com/upload/public/pdf/source/20170606/1496716524919.pdf
"Supplier" LCSC
"Add into BOM" yes
"Convert to PCB" yes
"3D Model" 185081e4ebbe4eaea4bbf508888b62e2
"3D Model Title" CONN-TH_XT60
"3D Model Transform" 610.235,319.291,0,0,0,0,0,0,-196.85
"Description" 模型锂电连接器 XT60-M
"Brand" 艾迈斯
"Model" XT60PW-M
"Power" -
"Output" -
"Input" -
"Size" -
"Interface" -
"Type" 卧式插头
"Colour" 黄色
"MaximumCurrent" -
"RatedVoltage" -
"Type1" -
"NumberOfUSBHoles" -
"InterfaceType" 公头
"MetalMaterial" -
"InsulationMaterial" -
"RatedCurrent" -
"RecommendedWireGauge" -
"FlameRetardantGrade" -
"contact resistance" -
"Belt length" -
"specifications" -
"Origin Footprint" TH_2P-XT60PW-F
"Unique ID" gge16
"Design Item ID" XT60PW-F
"Reuse Block" 
"Group ID" 
"Channel ID" 
0 50 10 0 4
1 50 10 0 4
OLED 2.54-1*4P母 2150 2450 0 0 100 10 100 10 3 40 4 0 0 6
"Default Font"
"Default Font"
-150 250 0 0 139 10 1 "Regular Times New Roman"
REF-DES
-150 -350 0 0 139 10 1 "Regular Times New Roman"
PART-TYPE
-150 -350 0 0 139 10 1 "Regular Times New Roman"
Name
"Name" 2.54-1*4P母
"Symbol" 2.54-1*4P母
"Device" 2.54-1*4P母
"PCB DECAL" HDR-TH_4P-P2.54-V-F
"Supplier" LCSC
"Supplier Part" C2718488
"Manufacturer" BOOMELE(博穆精密)
"Manufacturer Part" 2.54-1*4P母
"JLCPCB Part Class" Extended Part
"LCSC Part Name" 间距:2.54mm 1x4P 直插
"Supplier Footprint" 插件,P=2.54mm
"Datasheet" https://atta.szlcsc.com/upload/public/pdf/source/20210301/C2718488_F4427B881E42CAA8DDB0B1C12B3A522C.pdf
"Add into BOM" yes
"Convert to PCB" yes
"3D Model" 57daaad411c24bd7bd5d06edf5c4d16b
"3D Model Title" HDR-TH_4P-P2.54-F-LI-1X4P
"3D Model Transform" 415.7472,98.425,0,0,0,0,0,0,-118.11
"Number of Rows" 单排
"Number of Holes" 4P
"Pitch" 2.54mm
"Holes Structure" 1x4P
"Row Spacing" -
"Mounting Type" 直插
"Circular Hole / Square Hole" 方孔
"Current Rating (Max)" 3A
"Voltage Rating (Max)" -
"Holes Direction" 顶部
"Insulation Height" -
"Contact Material" 青铜
"Contact Plating" -
"Operating Temperature Range" -40℃~+105℃
"Welding Temperature (Max)" -
"Description" 排数:单排;总孔位数:4P;间距:2.54mm;插孔结构:1x4P;行距:-;安装类型:直插;圆孔/方孔:方孔;额定电流:3A;额定电压:-;插孔方向:顶部;塑高:-;触头材质:青铜;触头镀层:-;工作温度范围:-40℃~+105℃;焊接温度(最大值):-;
"Origin Footprint" SIP4
"Unique ID" 4fe8deccf3ecd12b
"Design Item ID" HEADER4
"Library Name" U_PP SCH
"Reuse Block" 
"Group ID" 
"Channel ID" 
0 50 10 0 4
1 50 10 0 4
2 50 10 0 4
3 50 10 0 4
C7 CC0603JRNPO9BN101 6300 5350 90 0 100 10 100 10 3 26 2 0 0 30
"Default Font"
"Default Font"
0 -150 90 3 139 10 1 "Regular 宋体"
REF-DES
-100 -150 90 3 139 10 1 "Regular 宋体"
PART-TYPE
-100 -150 90 3 139 10 1 "Regular 宋体"
Name
"Name" 100pF
"Symbol" CC0603JRNPO9BN101
"Device" CC0603JRNPO9BN101
"PCB DECAL" C0603
"Supplier" LCSC
"Manufacturer" YAGEO(国巨)
"Manufacturer Part" CC0603JRNPO9BN101
"Value" 100pF
"Supplier Part" C14665
"JLCPCB Part Class" Extended Part
"LCSC Part Name" 100pF ±5% 50V
"Supplier Footprint" 0603
"Datasheet" https://atta.szlcsc.com/upload/public/pdf/source/20181008/C309499_21CC21451B82C39E3D92150FD6B30293.pdf
"Add into BOM" yes
"Convert to PCB" yes
"3D Model" ac125912035d415993ca9572d50418b1
"3D Model Title" C0603_L1.6-W0.8-H0.8
"3D Model Transform" 62.992,31.496,0,0,0,0,0,0,0
"Tolerance" ±5%
"Voltage Rated" 50V
"Temperature Coefficient" NP0
"Description" 容值:100pF;精度:±5%;额定电压:50V;材质(温度系数):NP0;
"Reuse Block" 
"Group ID" 
"Channel ID" 
"Unique ID" gge15
0 50 10 0 4
1 50 10 0 4
R11 0603WAF2200T5E 6000 4700 0 3 100 10 100 10 3 29 2 0 0 30
"Default Font"
"Default Font"
100 -50 0 3 139 10 1 "Regular 宋体"
REF-DES
100 150 0 3 139 10 1 "Regular 宋体"
PART-TYPE
100 150 0 3 139 10 1 "Regular 宋体"
Name
"Name" 220Ω
"Symbol" 0603WAF2200T5E
"Device" 0603WAF2200T5E
"PCB DECAL" R0603
"Supplier" LCSC
"Manufacturer" UNI-ROYAL(厚声)
"Manufacturer Part" 0603WAF2200T5E
"Supplier Part" C22962
"Value" 220Ω
"JLCPCB Part Class" Basic Part
"LCSC Part Name" 220Ω ±1% 100mW 厚膜电阻
"Supplier Footprint" 0603
"Datasheet" https://atta.szlcsc.com/upload/public/pdf/source/20200306/C422600_1E6D84923E4A46A82E41ADD87F860B5C.pdf
"Add into BOM" yes
"Convert to PCB" yes
"3D Model" fc143cca1e79419f9cd78b61e9279f08
"3D Model Title" R0603
"3D Model Transform" 31.8897,63.7794,0,90,0,0,0,0,0
"Type" 厚膜电阻
"Tolerance" ±1%
"Power(Watts)" 100mW
"Overload Voltage (Max)" 75V
"Temperature Coefficient" ±100ppm/℃
"Operating Temperature Range" -55℃~+155℃
"Description" 电阻类型:厚膜电阻;阻值:220Ω;精度:±1%;功率:100mW;最大工作电压:75V;温度系数:±100ppm/℃;
"Reuse Block" 
"Group ID" 
"Channel ID" 
"Unique ID" gge17
0 50 10 0 4
1 50 10 0 4
UART PZ200V-11-06P 10650 3850 0 0 100 10 100 10 3 46 6 0 0 6
"Default Font"
"Default Font"
-100 350 0 0 139 10 1 "Regular Times New Roman"
REF-DES
-200 -550 0 0 139 10 1 "Regular Times New Roman"
PART-TYPE
-200 -550 0 0 139 10 1 "Regular Times New Roman"
Name
"Name" PZ200V-11-06P
"Symbol" PZ200V-11-06P
"Device" PZ200V-11-06P
"PCB DECAL" 6PIN-2MM-UART
"LCSC Part Name" 间距:2mm 1x6P 直插 方针
"Supplier Part" C541860
"Manufacturer" XFCN(兴飞)
"Manufacturer Part" PZ200V-11-06P
"Supplier Footprint" 插件,P=2mm
"JLCPCB Part Class" Extended Part
"Datasheet" https://atta.szlcsc.com/upload/public/pdf/source/20200518/C541858_7610F54454E936EFCDE06B655DF7C837.pdf
"Supplier" LCSC
"Add into BOM" yes
"Convert to PCB" yes
"3D Model" 5bc840b7798c448aa7498306b16b29ed
"3D Model Title" HDR-TH_6P-P2.00-M-LI-1X6P
"3D Model Transform" 472.44,78.74,0,0,0,0,0,0,-118.11
"Pin Structure" 1x6P
"Pitch" 2mm
"Row Spacing" -
"Circluar Pins/Square Pins" 方针
"Mounting Type" 直插
"Number of Rows" 单排
"Number of Pins" 6P
"Current Rating (Max)" -
"Voltage Rating (Max)" -
"Length of Mating Pin" 3.9mm
"Insulation Height" 2mm
"Length of End Connection Pin" 2.8mm
"Contact Material" 黄铜
"Contact Plating" -
"Operating Temperature Range" -40℃~+105℃
"Soldering Temperature(Max)" -
"Color" 黑色
"Description" 插针结构:1x6P;间距:2mm;行距:-;圆针/方针:方针;安装类型:直插;排数:单排;总PIN位数:6P;额定电流:-;额定电压:-;配合针长度:3.9mm;塑高:2mm;端接针长度:2.8mm;触头材质:黄铜;触头镀层:-;工作温度范围:-40℃~+105℃;焊接温度(最大值):-;颜色:黑色;
"Pins Structure" 1x3P
"Mounting Style" -
"Number of PINs Per Row" 3
"Reference Series" PH
"Origin Footprint" SIP3
"Unique ID" 12cb931c49908c91
"Design Item ID" HEADER 3
"Library Name" U_PP SCH
"Reuse Block" 
"Group ID" 
"Channel ID" 
0 50 10 0 4
1 50 10 0 4
2 50 10 0 4
3 50 10 0 4
4 50 10 0 4
5 50 10 0 4
S1 TS-1088-AR02016 7400 5400 0 0 100 10 100 10 3 41 2 0 0 14
"Default Font"
"Default Font"
-100 50 0 0 139 10 1 "Regular Times New Roman"
REF-DES
-250 -100 0 0 97 10 1 "Regular Times New Roman"
PART-TYPE
-250 -100 0 0 97 10 1 "Regular Times New Roman"
Name
"Name" TS-1088-AR02016
"Symbol" TS-1088-AR02016
"Device" TS-1088-AR02016
"PCB DECAL" SW-SMD_L3.9-W3.0-P4.45
"Supplier" LCSC
"Supplier Part" C720477
"Manufacturer" XUNPU(讯普)
"Manufacturer Part" TS-1088-AR02016
"JLCPCB Part Class" Extended Part
"LCSC Part Name" 4*3*2mm 立贴 轻触开关
"Supplier Footprint" SMD
"Datasheet" https://atta.szlcsc.com/upload/public/pdf/source/20200810/C720475_60D09DD6C54279ADDB2DC25100F1CC11.pdf
"Add into BOM" yes
"Convert to PCB" yes
"3D Model" b26698b69f274ffabef8a26c7d0e5dd1
"3D Model Title" SW-SMD_L3.9-W2.9-H2.0-LS4.8
"3D Model Transform" 188.976,114.174,0,0,0,0,0,0,0
"Circuit" 单刀单掷
"Actuator Style" 圆形按钮
"Switch Length" 4mm
"Switch Width" 3mm
"Switch Height" 2mm
"Strike Gundam" 不带
"Contact Current" 50mA
"Voltage Rating (DC)" 12V
"Mounting Style" 立贴
"Insulation Resistance" 100MΩ
"Actuator/Cap Color" 黑色
"Operating Force" 160gf
"Pin Style" SMD接片
"Mechanical Life" 10万次
"Operating Temperature" -30℃~+80℃
"Description" 电路结构:单刀单掷;按钮形状:圆形按钮;作用力:160gf;安装方式:立贴;开关长度:4mm;开关宽度:3mm;开关高度:2mm;带支架:不带;触点电流:50mA;额定电压(DC):12V;绝缘电阻:100MΩ;机械寿命:10万次;
"With Lamp" -
"Origin Footprint" KEY-3.6X6
"Unique ID" 0ac0bd892f9b1ec0
"Design Item ID" SW-PB
"Library Name" U_PP SCH
"Reuse Block" 
"Group ID" 
"Channel ID" 
0 50 10 0 4
1 50 10 0 4
S2 TS-1088-AR02016 7450 5150 0 0 100 10 100 10 3 41 2 0 0 14
"Default Font"
"Default Font"
-150 50 0 0 83 10 1 "Regular Times New Roman"
REF-DES
-250 -100 0 0 83 10 1 "Regular Times New Roman"
PART-TYPE
-250 -100 0 0 83 10 1 "Regular Times New Roman"
Name
"Name" TS-1088-AR02016
"Symbol" TS-1088-AR02016
"Device" TS-1088-AR02016
"PCB DECAL" SW-SMD_L3.9-W3.0-P4.45
"Supplier" LCSC
"Supplier Part" C720477
"Manufacturer" XUNPU(讯普)
"Manufacturer Part" TS-1088-AR02016
"JLCPCB Part Class" Extended Part
"LCSC Part Name" 4*3*2mm 立贴 轻触开关
"Supplier Footprint" SMD
"Datasheet" https://atta.szlcsc.com/upload/public/pdf/source/20200810/C720475_60D09DD6C54279ADDB2DC25100F1CC11.pdf
"Add into BOM" yes
"Convert to PCB" yes
"3D Model" b26698b69f274ffabef8a26c7d0e5dd1
"3D Model Title" SW-SMD_L3.9-W2.9-H2.0-LS4.8
"3D Model Transform" 188.976,114.174,0,0,0,0,0,0,0
"Circuit" 单刀单掷
"Actuator Style" 圆形按钮
"Switch Length" 4mm
"Switch Width" 3mm
"Switch Height" 2mm
"Strike Gundam" 不带
"Contact Current" 50mA
"Voltage Rating (DC)" 12V
"Mounting Style" 立贴
"Insulation Resistance" 100MΩ
"Actuator/Cap Color" 黑色
"Operating Force" 160gf
"Pin Style" SMD接片
"Mechanical Life" 10万次
"Operating Temperature" -30℃~+80℃
"Description" 电路结构:单刀单掷;按钮形状:圆形按钮;作用力:160gf;安装方式:立贴;开关长度:4mm;开关宽度:3mm;开关高度:2mm;带支架:不带;触点电流:50mA;额定电压(DC):12V;绝缘电阻:100MΩ;机械寿命:10万次;
"With Lamp" -
"Origin Footprint" KEY-3.6X6
"Unique ID" gge18
"Design Item ID" SW-PB
"Library Name" U_PP SCH
"Reuse Block" 
"Group ID" 
"Channel ID" 
0 50 10 0 4
1 50 10 0 4
C4 CL21A476MQYNNNE 6550 1600 90 3 100 10 100 10 3 32 2 0 0 30
"Default Font"
"Default Font"
50 100 90 0 139 10 1 "Regular Times New Roman"
REF-DES
150 50 90 0 139 10 1 "Regular Times New Roman"
PART-TYPE
150 50 90 0 139 10 1 "Regular Times New Roman"
Name
"Name" 47uF
"Symbol" CL21A476MQYNNNE
"Device" CL21A476MQYNNNE
"PCB DECAL" C0805
"Supplier" LCSC
"Manufacturer Part" CL21A476MQYNNNE
"Manufacturer" SAMSUNG(三星)
"Value" 47uF
"Supplier Part" C16780
"JLCPCB Part Class" Basic Part
"LCSC Part Name" 47uF ±20% 6.3V
"Supplier Footprint" 0805
"Datasheet" https://atta.szlcsc.com/upload/public/pdf/source/20160218/1457707763339.pdf
"Add into BOM" yes
"Convert to PCB" yes
"3D Model" 1ba041120af144c991958decab20d241
"3D Model Title" C0805_L2.0-W1.3-H1.3
"3D Model Transform" 78.74,51.181,0,0,0,0,0,0.0005,0
"Tolerance" ±20%
"Voltage Rated" 6.3V
"Temperature Coefficient" X5R
"Description" 容值:47uF;精度:±20%;额定电压:6.3V;材质(温度系数):X5R;
"Rated Voltage" 10V
"Equivalent Series Resistance(ESR)" 2.4Ω@100kHz
"Operating Temperature" -55℃~+125℃
"Origin Footprint" 1206C
"Unique ID" cc82bf2c2e22e605
"Design Item ID" Cap
"Library Name" Miscellaneous Devices
"Reuse Block" 
"Group ID" 
"Channel ID" 
0 50 10 0 4
1 50 10 0 4
C2 CapAcitance 4500 5450 90 0 100 10 100 10 3 26 2 0 0 30
"Default Font"
"Default Font"
0 -150 90 3 139 10 1 "Regular 宋体"
REF-DES
-100 -150 90 3 139 10 1 "Regular 宋体"
PART-TYPE
-100 -150 90 3 139 10 1 "Regular 宋体"
Name
"Name" 100pF
"Symbol" CapAcitance
"Device" CC0603JRNPO9BN101
"PCB DECAL" C0603
"LCSC Part Name" 100pF ±5% 50V
"Supplier Part" C14665
"Manufacturer" YAGEO(国巨)
"Manufacturer Part" CC0603JRNPO9BN101
"Supplier Footprint" 0603
"JLCPCB Part Class" Extended Part
"Datasheet" https://atta.szlcsc.com/upload/public/pdf/source/20181008/C309499_21CC21451B82C39E3D92150FD6B30293.pdf
"Supplier" LCSC
"Add into BOM" yes
"Convert to PCB" yes
"3D Model" ac125912035d415993ca9572d50418b1
"3D Model Title" C0603_L1.6-W0.8-H0.8
"3D Model Transform" 62.992,31.496,0,0,0,0,0,0,0
"Value" 100pF
"Tolerance" ±5%
"Voltage Rated" 50V
"Temperature Coefficient" NP0
"Description" 容值:100pF;精度:±5%;额定电压:50V;材质(温度系数):NP0;
"Reuse Block" 
"Group ID" 
"Channel ID" 
"Unique ID" gge14
0 50 10 0 4
1 50 10 0 4
D1 SMAJ15CA_C1509527 3500 1450 90 0 100 10 100 10 3 29 2 0 0 30
"Default Font"
"Default Font"
-50 200 90 3 139 10 1 "Regular 宋体"
REF-DES
-250 450 90 3 139 10 1 "Regular 宋体"
PART-TYPE
-250 450 90 3 139 10 1 "Regular 宋体"
Name
"Name" SMAJ12CA
"Symbol" SMAJ15CA_C1509527
"Device" SMAJ12CA_C698919
"PCB DECAL" SMA_L4.4-W2.6-LS5.0-BI
"LCSC Part Name" 双向TVS
"Supplier Part" C698919
"Manufacturer" YANGJIE(扬杰)
"Manufacturer Part" SMAJ12CA
"Supplier Footprint" SMA(DO-214AC)
"JLCPCB Part Class" Extended Part
"Datasheet" https://atta.szlcsc.com/upload/public/pdf/source/20190626/C400501_E5286E6D730C560E6135F16A39AD19AD.pdf
"Supplier" LCSC
"Add into BOM" yes
"Convert to PCB" yes
"3D Model" 88a0b00993434c679979bf3235683172
"3D Model Title" SMA_L4.3-W2.5-H2.1-LS5.0
"3D Model Transform" 204.724,98.425,0,0,0,0,0,0,0
"Reverse Stand-Off Voltage (Vrwm)" 12V
"Maximum Clamping Voltage" 19.9V
"Peak Pulse Current (Ipp)@10/1000us" 20.1A
"Peak Pulse Power Dissipation (Ppp)@10/1000us" 400W
"Breakdown Voltage" 13.3V
"Type" TVS
"Description" 反向截止电压(Vrwm):12V;最大钳位电压:19.9V;峰值脉冲电流(Ipp)@10/1000us:20.1A;峰值脉冲功率(Ppp)@10/1000us:400W;击穿电压:13.3V;
"Reverse Leakage Current (Ir)" 1uA
"Reuse Block" 
"Group ID" 
"Channel ID" 
"Unique ID" gge20
0 50 10 0 4
1 50 10 0 4
U7 VC060303A100DP 7450 1650 90 0 100 10 100 10 3 29 2 0 0 30
"Default Font"
"Default Font"
-250 200 90 3 139 10 1 "Regular 宋体"
REF-DES
-600 600 90 3 139 10 1 "Regular 宋体"
PART-TYPE
-600 600 90 3 139 10 1 "Regular 宋体"
Name
"Name" VC060303A100DP
"Symbol" VC060303A100DP
"Device" VC060303A100DP
"PCB DECAL" R0603
"Supplier" LCSC
"Supplier Part" C2655386
"Manufacturer" Kyocera AVX
"Manufacturer Part" VC060303A100DP
"JLCPCB Part Class" Extended Part
"LCSC Part Name" 0.1焦耳 0603压敏电阻
"Supplier Footprint" 0603
"Datasheet" https://atta.szlcsc.com/upload/public/pdf/source/20230606/F25ABC06DA1414494AF73C023401BE98.pdf
"Add into BOM" yes
"Convert to PCB" yes
"3D Model" fc143cca1e79419f9cd78b61e9279f08
"3D Model Title" R0603
"3D Model Transform" 31.8897,63.7794,0,90,0,0,0,0,0
"Varistor Voltage" 5V
"Clamping Voltage" -
"Allowable Voltage (DC)" 3.3V
"Allowable Voltage (AC)" 2.3V
"Peak Current" 30A
"Maximum Energy" 0.1J
"Typical Capatitance" 1.45nF@1kHz
"Description" 压敏电压:5V;钳位电压:-;最大工作电压(DC):3.3V;最大工作电压(AC):2.3V;
"Unique ID" gge19
"Reuse Block" 
"Group ID" 
"Channel ID" 
0 50 10 0 4
1 50 10 0 4
R12 电阻 7000 6200 90 0 100 10 100 10 3 29 2 0 0 30
"Default Font"
"Default Font"
0 -100 90 3 139 10 1 "Regular 宋体"
REF-DES
-100 -100 90 3 139 10 1 "Regular 宋体"
PART-TYPE
-100 -100 90 3 139 10 1 "Regular 宋体"
Name
"Name" 10kΩ
"Symbol" 电阻
"Device" 0603WAF1002T5E
"PCB DECAL" R0603
"LCSC Part Name" 厚膜电阻 10kΩ ±1% 100mW
"Supplier Part" C25804
"Manufacturer" UNI-ROYAL(厚声)
"Manufacturer Part" 0603WAF1002T5E
"Supplier Footprint" 0603
"JLCPCB Part Class" Basic Part
"Datasheet" https://atta.szlcsc.com/upload/public/pdf/source/20200306/C422600_1E6D84923E4A46A82E41ADD87F860B5C.pdf
"Supplier" LCSC
"Add into BOM" yes
"Convert to PCB" yes
"3D Model" fc143cca1e79419f9cd78b61e9279f08
"3D Model Title" R0603
"3D Model Transform" 31.8897,63.7794,0,90,0,0,0,0,0
"Value" 10kΩ
"Tolerance" ±1%
"Power(Watts)" 100mW
"Overload Voltage (Max)" 75V
"Temperature Coefficient" ±100ppm/℃
"Type" 厚膜电阻
"Operating Temperature Range" -55℃~+155℃
"Description" 电阻类型:厚膜电阻;阻值:10kΩ;精度:±1%;功率:100mW;最大工作电压:75V;温度系数:±100ppm/℃;
"Reuse Block" 
"Group ID" 
"Channel ID" 
"Unique ID" gge21
0 50 10 0 4
1 50 10 0 4
C8 100p 7000 5750 90 0 100 10 100 10 3 27 2 0 0 30
"Default Font"
"Default Font"
-0 -150 90 3 139 10 1 "Regular 宋体"
REF-DES
-100 -150 90 3 139 10 1 "Regular 宋体"
PART-TYPE
-100 -150 90 3 139 10 1 "Regular 宋体"
Name
"Name" 1uF
"Symbol" 100p
"Device" CC0603KRX5R8BB105
"PCB DECAL" C0603
"LCSC Part Name" 1uF ±10% 25V
"Supplier Part" C14664
"Manufacturer" YAGEO(国巨)
"Manufacturer Part" CC0603KRX5R8BB105
"Supplier Footprint" 0603
"JLCPCB Part Class" Extended Part
"Datasheet" https://atta.szlcsc.com/upload/public/pdf/source/20160606/1465200209684.pdf
"Supplier" LCSC
"Add into BOM" yes
"Convert to PCB" yes
"3D Model" ac125912035d415993ca9572d50418b1
"3D Model Title" C0603_L1.6-W0.8-H0.8
"3D Model Transform" 62.992,31.496,0,0,0,0,0,0,0
"Value" 1uF
"Tolerance" ±10%
"Voltage Rated" 25V
"Temperature Coefficient" X5R
"Description" 容值:1uF;精度:±10%;额定电压:25V;材质(温度系数):X5R;
"Origin Footprint" C1206
"Unique ID" gge22
"Reuse Block" 
"Group ID" 
"Channel ID" 
0 50 10 0 4
1 50 10 0 4
Q2 NPN 5400 5300 0 0 100 10 100 10 3 29 3 0 0 30
"Default Font"
"Default Font"
450 -100 0 0 139 10 1 "Regular Times New Roman"
REF-DES
-250 -550 0 0 139 10 1 "Regular Times New Roman"
PART-TYPE
-250 -550 0 0 139 10 1 "Regular Times New Roman"
Name
"Name" DTC143ZCA
"Symbol" NPN
"Device" DTC143ZCA_C15236
"PCB DECAL" SOT-23-3_L2.9-W1.3-P1.90-LS2.4-BR
"LCSC Part Name" 电流:100mA 耐压:50V
"Supplier Part" C15236
"Manufacturer" CJ(江苏长电/长晶)
"Manufacturer Part" DTC143ZCA
"Supplier Footprint" SOT-23
"JLCPCB Part Class" Extended Part
"Datasheet" https://atta.szlcsc.com/upload/public/pdf/source/20140809/1457707205046.pdf
"Supplier" LCSC
"Add into BOM" yes
"Convert to PCB" yes
"3D Model" c62791f0466c4ae2a892c056b845b0ca
"3D Model Title" SOT-23-3P_L2.9-W1.3-H1.0-LS2.4-P0.95
"3D Model Transform" 98.425,114.173,0,180,0,0,0.0005,-0.0005,0
"Power Dissipation (Pd)" 200mW
"Collector-Emitter Breakdown Voltage (Vceo)" 50V
"Transistor Type" 1个NPN-预偏置
"Collector Current (Ic)" 100mA
"Description" 功率(Pd):200mW;集射极击穿电压(Vceo):50V;晶体管类型:1个NPN-预偏置;集电极电流(Ic):100mA;
"Origin Footprint" SOT23
"Unique ID" gge23
"Design Item ID" NPN
"Library Name" U_PP SCH
"Reuse Block" 
"Group ID" 
"Channel ID" 
0 100 10 0 4
1 100 10 0 4
2 100 10 0 4
*BUSSES*
*OFFPAGE REFS*
@@@O0 AC_OK $OSR_SYMS 1200 4450 0 3 0
@@@O1 PS_ON_L $OSR_SYMS 2200 3700 0 0 2
@@@O2 +12V $PWR_SYMS 8050 2650 0 0 0
@@@O3 VCC_3V3 $PWR_SYMS 1950 2500 0 3 3
@@@O4 GND $PWR_SYMS 1950 2600 0 3 2
@@@O5 GND $PWR_SYMS 8150 2550 90 3 2
@@@O6 GND $PWR_SYMS 5600 1450 90 3 2
@@@O7 GND $PWR_SYMS 6550 1450 90 3 2
@@@O8 GND $PWR_SYMS 4175 1300 90 3 2
@@@O9 GND $PWR_SYMS 6200 950 90 3 2
@@@O10 GND $PWR_SYMS 7000 1450 90 3 2
@@@O11 VCC_3V3 $PWR_SYMS 7450 1750 90 0 3
@@@O12 +12VSB $PWR_SYMS 3400 1650 0 3 1
@@@O13 GND $PWR_SYMS 7950 5950 0 3 2
@@@O14 GND $PWR_SYMS 9900 6050 0 0 2
@@@O15 GND $PWR_SYMS 9800 4050 90 3 2
@@@O16 PS_ON_L $OSR_SYMS 3850 4600 0 0 3
@@@O17 SGND $PWR_SYMS 4850 3500 90 3 2
@@@O18 +12V $PWR_SYMS 10150 2500 0 2 0
@@@O19 +12V $PWR_SYMS 10150 1950 0 2 0
@@@O20 +12V $PWR_SYMS 10150 1400 0 2 0
@@@O21 +12V $PWR_SYMS 10150 900 0 2 0
@@@O22 GND $PWR_SYMS 10250 800 90 3 2
@@@O23 GND $PWR_SYMS 10250 1300 90 3 2
@@@O24 GND $PWR_SYMS 10250 1850 90 3 2
@@@O25 GND $PWR_SYMS 10250 2400 90 3 2
@@@O26 AC_OK $OSR_SYMS 3850 5700 0 0 1
@@@O27 +12V $PWR_SYMS 850 6350 0 3 0
@@@O28 +12V $PWR_SYMS 2350 6350 0 0 0
@@@O29 GND $PWR_SYMS 750 5350 90 3 2
@@@O30 GND $PWR_SYMS 2450 5550 90 3 2
@@@O31 +12VSB $PWR_SYMS 2350 5100 0 0 0
@@@O32 PS_PRESENT $OSR_SYMS 1150 4800 0 0 4
@@@O33 PS_PRESENT $OSR_SYMS 5400 6550 0 0 4
@@@O34 +12VSB $PWR_SYMS 5650 7000 0 3 1
@@@O35 PS_KILL_L $OSR_SYMS 2200 3800 0 0 2
@@@O36 ISHARE $OSR_SYMS 1200 4200 0 3 0
@@@O37 PSINTERRUPT_L $OSR_SYMS 1200 4050 0 3 0
@@@O38 REMOTESENSE- $OSR_SYMS 2200 4550 0 0 2
@@@O39 REMOTESENSE+ $OSR_SYMS 2200 4750 0 0 2
@@@O40 +12V $PWR_SYMS 8050 2100 0 0 0
@@@O41 GND $PWR_SYMS 8150 2000 90 3 2
@@@O42 +12V $PWR_SYMS 8050 1550 0 0 0
@@@O43 GND $PWR_SYMS 8150 1450 90 3 2
@@@O44 PS_KILL_L $OSR_SYMS 5650 5550 0 3 2
@@@O45 VCC_3V3 $PWR_SYMS 7000 6350 90 0 3
@@@O46 VCC_3V3 $PWR_SYMS 9800 3600 90 0 3
@@@O47 GND $PWR_SYMS 7050 5300 90 3 2
@@@O48 GND $PWR_SYMS 7150 5050 90 3 2
@@@O49 GND $PWR_SYMS 7450 1350 90 3 2
@@@O50 GND $PWR_SYMS 3500 1250 90 3 2
@@@O51 GND $PWR_SYMS 6000 6000 90 3 2
@@@O52 VCC_3V3 $PWR_SYMS 7600 6350 90 0 3
@@@O53 GND $PWR_SYMS 7000 5550 90 3 2
@@@O54 SW2 @TERM 5050 5100 0 0 -2
@@@O55 SW2 @TERM 7800 5350 0 0 -2
@@@O56 SW @TERM 7800 5450 0 0 -2
@@@O57 PS_KILL_L @TERM 6650 5550 0 0 -2
@@@O58 SDA @TERM 9250 3550 0 0 -2
@@@O59 SCL @TERM 9350 3550 0 0 -2
@@@O60 SDA_OLED @TERM 8350 3550 0 0 -2
@@@O61 EN @TERM 10050 3900 0 0 -2
@@@O62 BOOT @TERM 10050 4000 0 0 -2
@@@O63 BOOT @TERM 10200 4650 0 0 -2
@@@O64 SGND @TERM 6300 4550 0 0 -2
@@@O65 SGND @TERM 4850 3750 0 0 -2
@@@O66 AC_OK @TERM 4850 5700 0 0 -2
@@@O67 SGND @TERM 4100 5150 0 0 -2
@@@O68 SGND @TERM 950 4300 0 0 -2
@@@O69 SGND @TERM 950 3900 0 0 -2
@@@O70 SGND @TERM 2500 4600 0 0 -2
@@@O71 SGND @TERM 2500 4400 0 0 -2
@@@O72 SGND @TERM 2500 4200 0 0 -2
@@@O73 SGND @TERM 2500 4000 0 0 -2
@@@O74 SW @TERM 5150 4050 0 0 -2
@@@O75 SW @TERM 5700 4050 0 0 -2
@@@O76 RX0 @TERM 10050 3800 0 0 -2
@@@O77 TX0 @TERM 10050 3700 0 0 -2
@@@O78 RX0 @TERM 10350 5550 0 0 -2
@@@O79 TX0 @TERM 10350 5650 0 0 -2
@@@O80 SCL_OLED @TERM 10350 5750 0 0 -2
@@@O81 SCL @TERM 2500 4300 0 0 -2
@@@O82 SDA @TERM 2500 4100 0 0 -2
@@@O83 SDA_OLED @TERM 950 2300 0 0 -2
@@@O84 SCL_OLED @TERM 950 2400 0 0 -2
*TIEDOTS*
@@@D0 7000 5950
@@@D1 6300 5550
@@@D2 5700 5550
@@@D3 6300 4700
@@@D4 4850 3650
@@@D5 4150 5700
@@@D6 4500 5700
@@@D7 4150 5250
@@@D8 6000 6000
@@@D9 5650 6550
@@@D10 5650 6550
@@@D11 2100 5100
@@@D12 2100 5550
@@@D13 2100 5600
@@@D14 2100 5700
@@@D15 2100 5800
@@@D16 2100 5500
@@@D17 2100 5400
@@@D18 2100 5300
@@@D19 1300 5350
@@@D20 1300 5400
@@@D21 1300 5500
@@@D22 1300 5600
@@@D23 1300 5700
@@@D24 1300 5800
@@@D25 1300 5300
@@@D26 1300 5200
@@@D27 1300 5100
@@@D28 2100 6350
@@@D29 2100 6300
@@@D30 2100 6200
@@@D31 2100 6100
@@@D32 2100 6400
@@@D33 2100 6500
@@@D34 2100 6600
@@@D35 1300 6350
@@@D36 1300 6400
@@@D37 1300 6500
@@@D38 1300 6600
@@@D39 1300 6300
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
*CONNECTION*
*SIGNAL* SW2 0 0
@@@O54 Q2.1 2 0
5050 5100
5200 5100
@@@O55 U2.7 2 0
7800 5350
7950 5350
*SIGNAL* GND 0 0
@@@O53 C8.1 2 0
7000 5550
7000 5550
@@@O50 D1.1 2 0
3500 1250
3500 1250
@@@O49 U7.1 2 0
7450 1350
7450 1350
S2.1 @@@O48 2 0
7150 5150
7150 5050
@@@O47 S1.1 3 0
7050 5300
7050 5400
7100 5400
@@@O4 OLED.1 2 0
1950 2600
1950 2600
U6.1 @@@O43 2 0
8050 1450
8150 1450
U5.1 @@@O41 2 0
8050 2000
8150 2000
@@@O5 U4.1 2 0
8150 2550
8050 2550
@@@D8 @@@O51 2 0
6000 6000
6000 6000
R4.1 @@@D8 3 0
5650 6100
5650 6000
6000 6000
@@@D8 C1.2 2 0
6000 6000
6000 6100
@@@O30 @@@D12 2 0
2450 5550
2100 5550
@@@D13 U1.P25 2 0
2100 5600
2100 5600
@@@D13 @@@D12 2 0
2100 5600
2100 5550
@@@D14 U1.P26 2 0
2100 5700
2100 5700
@@@D14 @@@D13 2 0
2100 5700
2100 5600
@@@D15 U1.P27 2 0
2100 5800
2100 5800
@@@D15 @@@D14 2 0
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
DC1.4 @@@O25 2 0
10150 2400
10250 2400
DC2.4 @@@O24 2 0
10150 1850
10250 1850
DC3.4 @@@O23 2 0
10150 1300
10250 1300
DC4.4 @@@O22 2 0
10150 800
10250 800
@@@O13 U2.1 2 0
7950 5950
7950 5950
@@@O10 C6.1 2 0
7000 1450
7000 1450
@@@O7 C4.2 2 0
6550 1450
6550 1450
@@@O8 C5.2 2 0
4175 1300
4175 1300
@@@O9 R10.1 2 0
6200 950
6200 950
@@@D43 @@@O14 2 0
9900 6050
9900 6050
U2.41 @@@D43 2 0
9750 6050
9900 6050
@@@D43 U2.40 3 0
9900 6050
9900 5950
9750 5950
UART.GND @@@O15 3 0
10450 4100
9800 4100
9800 4050
U3.1 @@@O6 3 0
5550 1550
5600 1550
5600 1450
*SIGNAL* VCC_3V3 0 0
U2.2 @@@O52 3 0
7950 5850
7600 5850
7600 6350
@@@O45 R12.2 2 0
7000 6350
7000 6400
UART.VCC @@@O46 2 0
10450 3600
9800 3600
@@@O3 OLED.2 2 0
1950 2500
1950 2500
*SIGNAL* PS_ON_L 0 0
Q1.3 @@@O16 3 0
4850 4450
4850 4600
3850 4600
@@@O1 U1.S13 2 0
2200 3700
2100 3700
*SIGNAL* SW 0 0
U2.6 @@@O56 2 0
7950 5450
7800 5450
@@@D44 Q1.1 2 0
5350 4050
5350 4050
@@@D44 @@@O74 2 0
5350 4050
5150 4050
@@@O75 @@@D44 2 0
5700 4050
5350 4050
*SIGNAL* EN 0 0
@@@D0 C8.2 2 0
7000 5950
7000 5950
@@@D0 R12.1 2 0
7000 5950
7000 6000
@@@D0 U2.3 4 0
7000 5950
7450 5950
7450 5750
7950 5750
UART.EN @@@O61 2 0
10450 3900
10050 3900
*SIGNAL* PS_KILL_L 0 0
@@@D1 C7.2 2 0
6300 5550
6300 5550
@@@O57 @@@D1 2 0
6650 5550
6300 5550
@@@D1 @@@D2 2 0
6300 5550
5700 5550
@@@O44 @@@D2 2 0
5650 5550
5700 5550
@@@D2 Q2.3 2 0
5700 5550
5700 5500
U1.S14 @@@O35 2 0
2100 3800
2200 3800
*SIGNAL* SDA 0 0
U2.24 @@@O58 2 0
9250 4150
9250 3550
@@@O82 U1.S17 2 0
2500 4100
2100 4100
*SIGNAL* SCL 0 0
@@@O59 U2.25 2 0
9350 3550
9350 4150
@@@O81 U1.S19 2 0
2500 4300
2100 4300
*SIGNAL* $$$0 0 0
U2.4 S1.2 3 0
7950 5650
7700 5650
7700 5400
U2.5 S2.2 3 0
7950 5550
7750 5550
7750 5150
C3.1 U3.6 4 0
5050 2000
4800 2000
4800 1750
4850 1750
C5.1 @@@D49 2 0
4175 1600
4175 1650
R7.1 @@@D49 2 0
3975 1650
4175 1650
@@@D50 R9.2 2 0
4425 1650
4425 1650
@@@D49 @@@D50 2 0
4175 1650
4425 1650
@@@D50 U3.3 2 0
4425 1650
4850 1650
@@@D51 R10.2 2 0
6200 1350
6200 1350
@@@D51 R8.1 2 0
6200 1350
6200 1350
U3.4 @@@D51 4 0
5550 1650
5800 1650
5800 1350
6200 1350
R9.1 U3.5 4 0
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
*SIGNAL* SDA_OLED 0 0
@@@O60 U2.15 2 0
8350 3550
8350 4150
OLED.4 @@@O83 2 0
1950 2300
950 2300
*SIGNAL* BOOT 0 0
UART.BOOT @@@O62 2 0
10450 4000
10050 4000
@@@O63 U2.27 2 0
10200 4650
9750 4650
*SIGNAL* SGND 0 0
C7.1 @@@D3 2 0
6300 5150
6300 4700
@@@D3 R11.1 2 0
6300 4700
6200 4700
@@@O64 @@@D3 2 0
6300 4550
6300 4700
@@@D4 Q1.2 2 0
4850 3650
4850 3650
@@@O17 @@@D4 2 0
4850 3500
4850 3650
@@@D4 @@@O65 2 0
4850 3650
4850 3750
@@@D7 @@@O67 3 0
4150 5250
4100 5250
4100 5150
@@@D7 R6.2 2 0
4150 5250
4150 5300
C2.1 @@@D7 2 0
4500 5250
4150 5250
@@@O68 U1.S6 2 0
950 4300
1300 4300
U1.S10 @@@O69 2 0
1300 3900
950 3900
U1.S22 @@@O70 2 0
2100 4600
2500 4600
U1.S20 @@@O71 2 0
2100 4400
2500 4400
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
*SIGNAL* +12V 0 0
U6.2 @@@O42 2 0
8050 1550
8050 1550
U5.2 @@@O40 2 0
8050 2100
8050 2100
@@@O2 U4.2 2 0
8050 2650
8050 2650
@@@O28 @@@D28 2 0
2350 6350
2100 6350
@@@D29 U1.P32 2 0
2100 6300
2100 6300
@@@D28 @@@D29 2 0
2100 6350
2100 6300
@@@D30 U1.P31 2 0
2100 6200
2100 6200
@@@D29 @@@D30 2 0
2100 6300
2100 6200
@@@D31 U1.P30 2 0
2100 6100
2100 6100
@@@D30 @@@D31 2 0
2100 6200
2100 6100
@@@D31 U1.P29 2 0
2100 6100
2100 6000
@@@D32 U1.P33 2 0
2100 6400
2100 6400
@@@D32 @@@D28 2 0
2100 6400
2100 6350
@@@D33 U1.P34 2 0
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
@@@O21 DC4.3 2 0
10150 900
10150 900
@@@O20 DC3.3 2 0
10150 1400
10150 1400
DC2.3 @@@O19 2 0
10150 1950
10150 1950
@@@O18 DC1.3 2 0
10150 2500
10150 2500
*SIGNAL* AC_OK 0 0
@@@D5 R6.1 2 0
4150 5700
4150 5700
@@@O26 @@@D5 2 0
3850 5700
4150 5700
@@@D5 @@@D6 2 0
4150 5700
4500 5700
@@@D6 C2.2 2 0
4500 5700
4500 5650
@@@D6 @@@O66 2 0
4500 5700
4850 5700
U1.S5 @@@O0 3 0
1300 4400
1200 4400
1200 4450
*SIGNAL* REMOTESENSE+ 0 0
@@@O39 U1.S23 3 0
2200 4750
2200 4700
2100 4700
*SIGNAL* REMOTESENSE- 0 0
@@@O38 U1.S21 3 0
2200 4550
2100 4550
2100 4500
*SIGNAL* PSINTERRUPT_L 0 0
@@@O37 U1.S9 3 0
1200 4050
1200 4000
1300 4000
*SIGNAL* ISHARE 0 0
U1.S7 @@@O36 2 0
1300 4200
1200 4200
*SIGNAL* +12VSB 0 0
@@@O34 R1.2 2 0
5650 7000
5650 7000
@@@D11 U1.P20 2 0
2100 5100
2100 5100
U1.P19 @@@D11 2 0
2100 5000
2100 5100
@@@D11 @@@O31 2 0
2100 5100
2350 5100
@@@D42 D1.2 2 0
3500 1650
3500 1650
R7.2 @@@D42 2 0
3575 1650
3500 1650
@@@O12 @@@D42 2 0
3400 1650
3500 1650
*SIGNAL* PS_PRESENT 0 0
@@@D9 @@@D10 2 0
5650 6550
5650 6550
@@@D9 @@@O33 2 0
5650 6550
5400 6550
@@@D9 R1.1 2 0
5650 6550
5650 6600
@@@D10 R4.2 2 0
5650 6550
5650 6500
C1.1 @@@D10 3 0
6000 6500
6000 6550
5650 6550
@@@O32 U1.S1 2 0
1150 4800
1300 4800
*SIGNAL* RX0 0 0
@@@O76 UART.RXD 2 0
10050 3800
10450 3800
U2.36 @@@O78 3 0
9750 5550
9900 5550
10350 5550
*SIGNAL* TX0 0 0
@@@O77 UART.TXD 2 0
10050 3700
10450 3700
U2.37 @@@O79 3 0
9750 5650
9900 5650
10350 5650
*SIGNAL* SCL_OLED 0 0
U2.38 @@@O80 3 0
9750 5750
9900 5750
10350 5750
OLED.3 @@@O84 2 0
1950 2400
950 2400
*SIGNAL* [] 0 0
@@@D45 R8.2 2 0
6200 1750
6200 1750
@@@D46 C4.1 2 0
6550 1750
6550 1750
@@@D45 @@@D46 2 0
6200 1750
6550 1750
L1.2 @@@D45 2 0
6075 1750
6200 1750
@@@D47 C6.2 2 0
7000 1750
7000 1750
@@@D46 @@@D47 2 0
6550 1750
7000 1750
@@@D48 @@@O11 2 0
7450 1750
7450 1750
@@@D48 U7.2 2 0
7450 1750
7450 1750
@@@D47 @@@D48 2 0
7000 1750
7450 1750
*NETNAMES*
AC_OK @@@O0 -360 45 0 6 0      0      0 0 -1 10 97 "Regular DOUYU Font"
PS_ON_L @@@O1 360 -45 0 4 0      0      0 0 -1 10 97 "Regular DOUYU Font"
+12V @@@O2 120 45 0 2 0      0      0 0 -1 10 97 "Regular DOUYU Font"
VCC_3V3 @@@O3 -120 50 0 3 0      0      0 0 -1 10 97 "Regular DOUYU Font"
GND @@@O4 -120 50 0 3 0      0      0 0 -1 10 97 "Regular DOUYU Font"
GND @@@O5 0 -220 0 4 0      0      0 0 -1 10 97 "Regular DOUYU Font"
GND @@@O6 0 -210 0 4 0      0      0 0 -1 10 97 "Regular DOUYU Font"
GND @@@O7 0 -210 0 4 0      0      0 0 -1 10 97 "Regular DOUYU Font"
GND @@@O8 0 -210 0 4 0      0      0 0 -1 10 97 "Regular DOUYU Font"
GND @@@O9 0 -210 0 4 0      0      0 0 -1 10 97 "Regular DOUYU Font"
GND @@@O10 0 -210 0 4 0      0      0 0 -1 10 97 "Regular DOUYU Font"
VCC_3V3 @@@O11 0 120 0 4 0      0      0 0 -1 10 97 "Regular DOUYU Font"
+12VSB @@@O12 -120 -50 0 1 0      0      0 0 -1 10 97 "Regular DOUYU Font"
GND @@@O13 -120 -50 0 1 0      0      0 0 -1 10 97 "Regular DOUYU Font"
GND @@@O14 120 -50 0 0 0      0      0 0 -1 10 97 "Regular DOUYU Font"
GND @@@O15 0 -220 0 4 0      0      0 0 -1 10 97 "Regular DOUYU Font"
PS_ON_L @@@O16 -360 -45 0 4 0      0      0 0 -1 10 97 "Regular DOUYU Font"
SGND @@@O17 0 -220 0 4 0      0      0 0 -1 10 97 "Regular DOUYU Font"
+12V @@@O18 120 -45 0 0 0      0      0 0 -1 10 97 "Regular DOUYU Font"
+12V @@@O19 120 -45 0 0 0      0      0 0 -1 10 97 "Regular DOUYU Font"
+12V @@@O20 120 -45 0 0 0      0      0 0 -1 10 97 "Regular DOUYU Font"
+12V @@@O21 120 -45 0 0 0      0      0 0 -1 10 97 "Regular DOUYU Font"
GND @@@O22 0 -220 0 4 0      0      0 0 -1 10 97 "Regular DOUYU Font"
GND @@@O23 0 -220 0 4 0      0      0 0 -1 10 97 "Regular DOUYU Font"
GND @@@O24 0 -220 0 4 0      0      0 0 -1 10 97 "Regular DOUYU Font"
GND @@@O25 0 -220 0 4 0      0      0 0 -1 10 97 "Regular DOUYU Font"
AC_OK @@@O26 -360 -45 0 4 0      0      0 0 -1 10 97 "Regular DOUYU Font"
+12V @@@O27 -120 -45 0 1 0      0      0 0 -1 10 97 "Regular DOUYU Font"
+12V @@@O28 120 -45 0 0 0      0      0 0 -1 10 97 "Regular DOUYU Font"
GND @@@O29 0 -220 0 4 0      0      0 0 -1 10 97 "Regular DOUYU Font"
GND @@@O30 0 -220 0 4 0      0      0 0 -1 10 97 "Regular DOUYU Font"
+12VSB @@@O31 120 -45 0 0 0      0      0 0 -1 10 97 "Regular DOUYU Font"
PS_PRESENT @@@O32 -280 -45 0 4 0      0      0 0 -1 10 97 "Regular DOUYU Font"
PS_PRESENT @@@O33 -280 -45 0 4 0      0      0 0 -1 10 97 "Regular DOUYU Font"
+12VSB @@@O34 -120 -45 0 1 0      0      0 0 -1 10 97 "Regular DOUYU Font"
PS_KILL_L @@@O35 360 -45 0 4 0      0      0 0 -1 10 97 "Regular DOUYU Font"
ISHARE @@@O36 -360 45 0 6 0      0      0 0 -1 10 97 "Regular DOUYU Font"
PSINTERRUPT_L @@@O37 -360 45 0 6 0      0      0 0 -1 10 97 "Regular DOUYU Font"
REMOTESENSE- @@@O38 360 -45 0 4 0      0      0 0 -1 10 97 "Regular DOUYU Font"
REMOTESENSE+ @@@O39 360 -45 0 4 0      0      0 0 -1 10 97 "Regular DOUYU Font"
+12V @@@O40 120 45 0 2 0      0      0 0 -1 10 97 "Regular DOUYU Font"
GND @@@O41 0 -220 0 4 0      0      0 0 -1 10 97 "Regular DOUYU Font"
+12V @@@O42 120 45 0 2 0      0      0 0 -1 10 97 "Regular DOUYU Font"
GND @@@O43 0 -220 0 4 0      0      0 0 -1 10 97 "Regular DOUYU Font"
PS_KILL_L @@@O44 -360 45 0 6 0      0      0 0 -1 10 97 "Regular DOUYU Font"
VCC_3V3 @@@O45 0 120 0 4 0      0      0 0 -1 10 97 "Regular DOUYU Font"
VCC_3V3 @@@O46 0 120 0 4 0      0      0 0 -1 10 97 "Regular DOUYU Font"
GND @@@O47 -100 -200 0 0 0      0      0 0 -1 10 97 "Regular DOUYU Font"
GND @@@O48 -100 -200 0 0 0      0      0 0 -1 10 97 "Regular DOUYU Font"
GND @@@O49 0 -210 0 4 0      0      0 0 -1 10 97 "Regular DOUYU Font"
GND @@@O50 0 -210 0 4 0      0      0 0 -1 10 97 "Regular DOUYU Font"
GND @@@O51 0 -210 0 4 0      0      0 0 -1 10 97 "Regular DOUYU Font"
VCC_3V3 @@@O52 0 120 0 4 0      0      0 0 -1 10 97 "Regular DOUYU Font"
GND @@@O53 -100 -200 0 0 0      0      0 0 -1 10 97 "Regular DOUYU Font"
SW2 @@@O54 0 0 0 0 0      0      0 0 -1 10 97 "Regular DOUYU Font"
SW2 @@@O55 0 0 0 0 0      0      0 0 -1 10 97 "Regular DOUYU Font"
SW U2.6 -150 0 0 0 0      0      0 0 -1 10 97 "Regular DOUYU Font"
EN U2.3 -850 200 0 0 0      0      0 0 -1 10 97 "Regular DOUYU Font"
PS_KILL_L Q2.3 600 50 0 0 0      0      0 0 -1 10 97 "Regular DOUYU Font"
SDA U2.24 0 -550 90 0 0      0      0 0 -1 10 97 "Regular DOUYU Font"
SCL @@@O59 0 50 90 0 0      0      0 0 -1 10 97 "Regular DOUYU Font"
$$$0 U2.4 -125 0 0 0 0      0      0 0 -1 10 97 "Regular DOUYU Font"
$$$0 U2.5 -50 0 0 0 0      0      0 0 -1 10 97 "Regular DOUYU Font"
SDA_OLED @@@O60 0 50 90 0 0      0      0 0 -1 10 97 "Regular DOUYU Font"
EN UART.EN -350 0 0 0 0      0      0 0 -1 10 97 "Regular DOUYU Font"
BOOT UART.BOOT -350 0 0 0 0      0      0 0 -1 10 97 "Regular DOUYU Font"
BOOT @@@O63 -300 0 0 0 0      0      0 0 -1 10 97 "Regular DOUYU Font"
SGND R11.1 100 -150 0 0 0      0      0 0 -1 10 97 "Regular DOUYU Font"
AC_OK C2.2 50 50 0 0 0      0      0 0 -1 10 97 "Regular DOUYU Font"
SGND R6.2 -50 -150 0 0 0      0      0 0 -1 10 97 "Regular DOUYU Font"
SGND @@@O68 0 0 0 0 0      0      0 0 -1 10 97 "Regular DOUYU Font"
SGND U1.S10 -350 0 0 0 0      0      0 0 -1 10 97 "Regular DOUYU Font"
SGND U1.S22 200 0 0 0 0      0      0 0 -1 10 97 "Regular DOUYU Font"
SGND U1.S20 200 0 0 0 0      0      0 0 -1 10 97 "Regular DOUYU Font"
SGND U1.S18 200 0 0 0 0      0      0 0 -1 10 97 "Regular DOUYU Font"
SGND U1.S16 200 0 0 0 0      0      0 0 -1 10 97 "Regular DOUYU Font"
SW @@@O75 -200 0 0 0 0      0      0 0 -1 10 97 "Regular DOUYU Font"
RX0 @@@O76 50 0 0 0 0      0      0 0 -1 10 97 "Regular DOUYU Font"
TX0 @@@O77 50 0 0 0 0      0      0 0 -1 10 97 "Regular DOUYU Font"
RX0 U2.36 150 0 0 0 0      0      0 0 -1 10 97 "Regular DOUYU Font"
TX0 U2.37 150 0 0 0 0      0      0 0 -1 10 97 "Regular DOUYU Font"
SCL_OLED U2.38 150 0 0 0 0      0      0 0 -1 10 97 "Regular DOUYU Font"
SCL @@@O81 -150 0 0 0 0      0      0 0 -1 10 97 "Regular DOUYU Font"
SDA @@@O82 -150 0 0 0 0      0      0 0 -1 10 97 "Regular DOUYU Font"
SDA_OLED OLED.4 -550 0 0 0 0      0      0 0 -1 10 97 "Regular DOUYU Font"
SCL_OLED OLED.3 -550 0 0 0 0      0      0 0 -1 10 97 "Regular DOUYU Font"

*END*

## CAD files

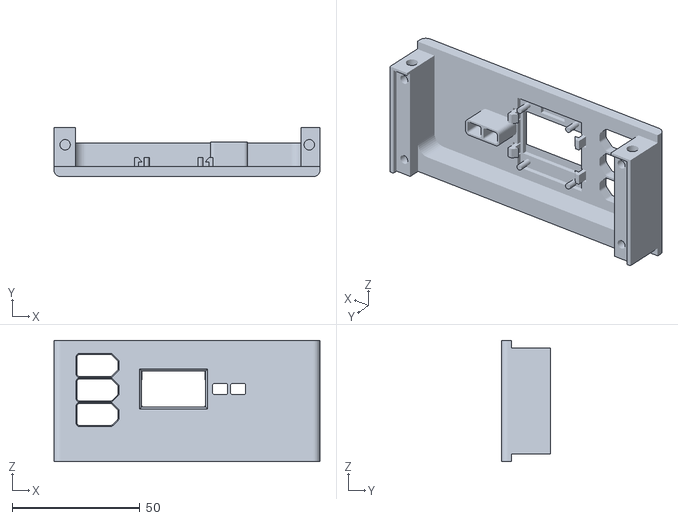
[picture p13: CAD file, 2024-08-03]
3DModels/MYNOVA-SmartPower_STL/Full-Front.stl
104.0 x 19.2 x 47.5

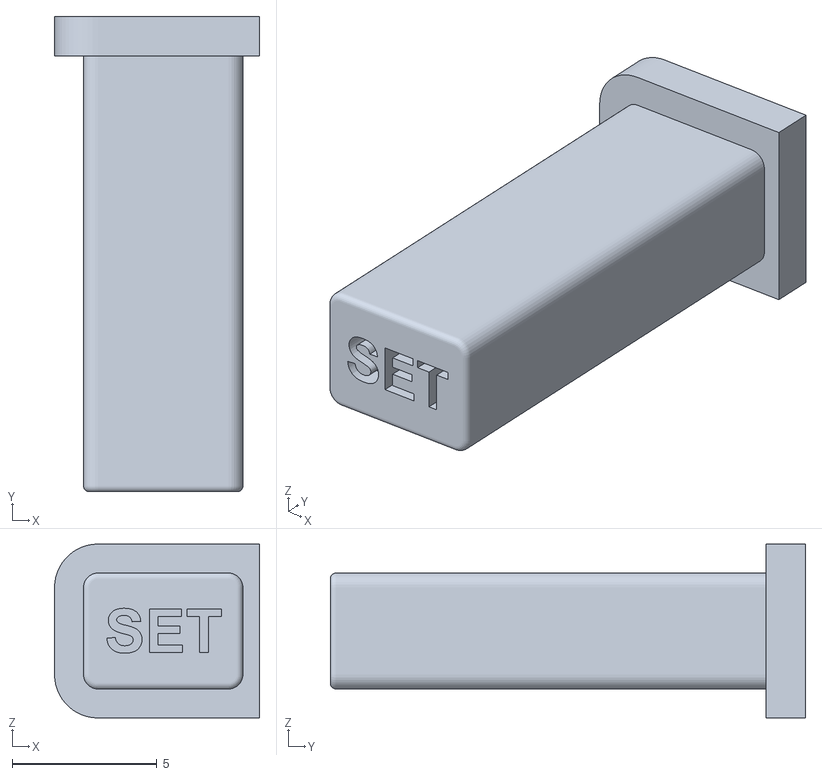
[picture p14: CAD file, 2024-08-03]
3DModels/MYNOVA-SmartPower_STL/Full-Btn_Left.stl
7.07 x 16.4 x 6.00

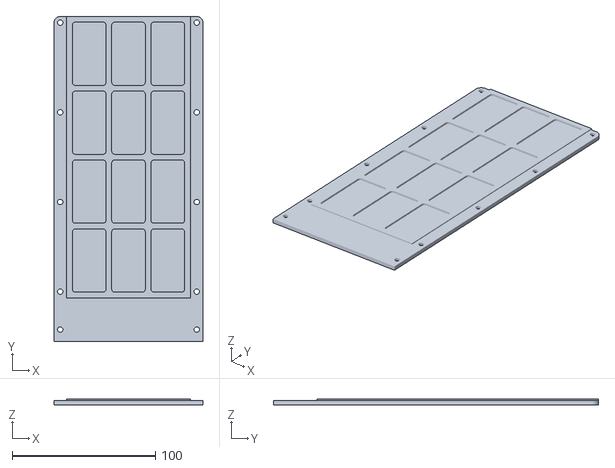
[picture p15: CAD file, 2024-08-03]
3DModels/MYNOVA-SmartPower_STL/Full-Bottom.stl
104.0 x 227.0 x 4.00

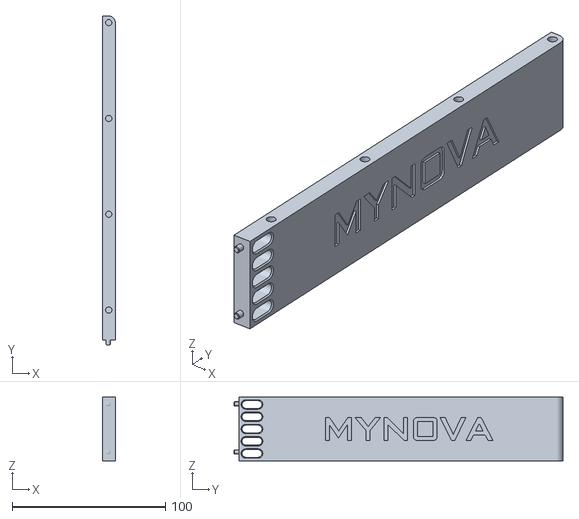
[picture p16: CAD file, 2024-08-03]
3DModels/MYNOVA-SmartPower_STL/Full-Slide-R.stl
8.35 x 215.0 x 41.5

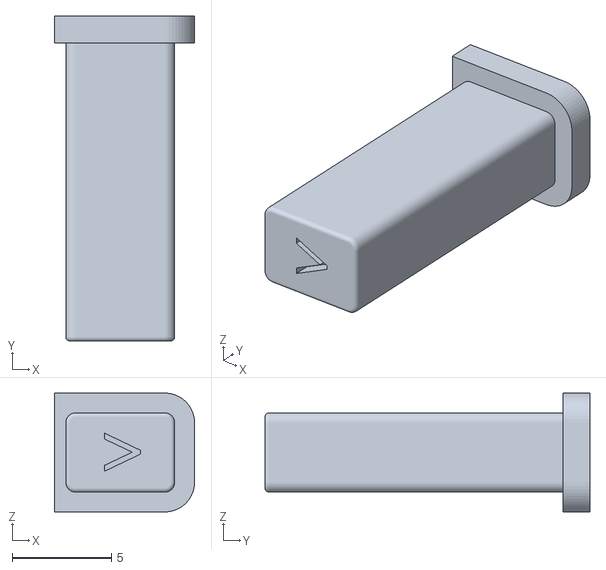
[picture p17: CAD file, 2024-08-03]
3DModels/MYNOVA-SmartPower_STL/Full-Btn_Right.stl
7.07 x 16.4 x 6.00

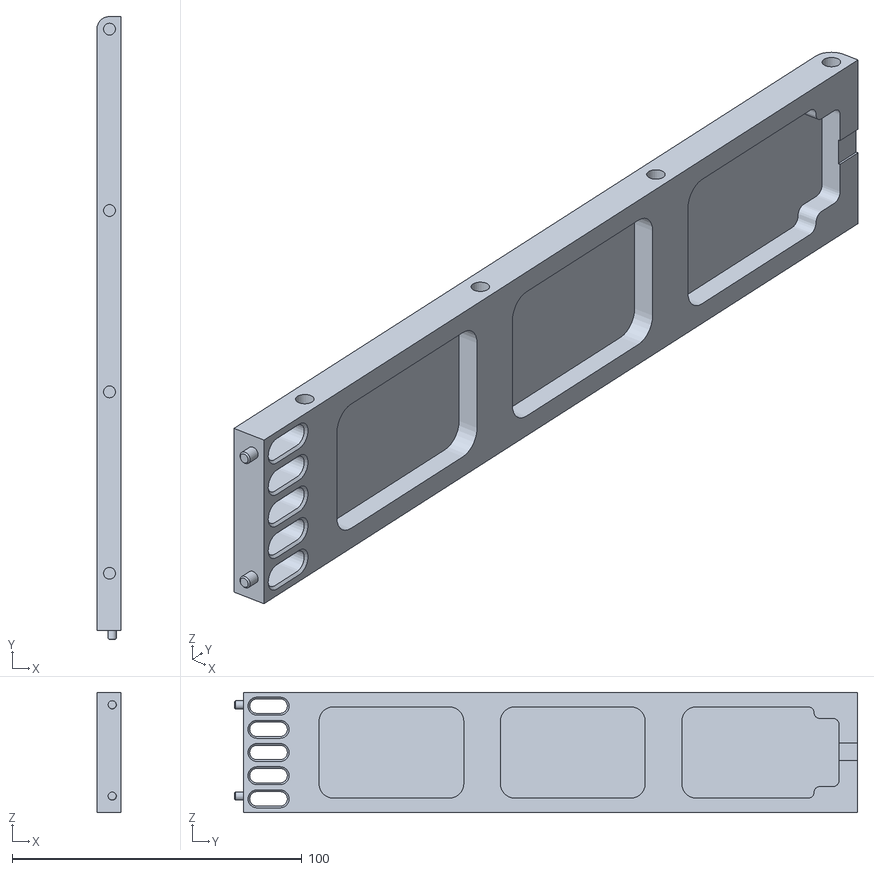
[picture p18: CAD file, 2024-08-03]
3DModels/MYNOVA-SmartPower_STL/Full-Slide-L.stl
8.35 x 215.0 x 41.5

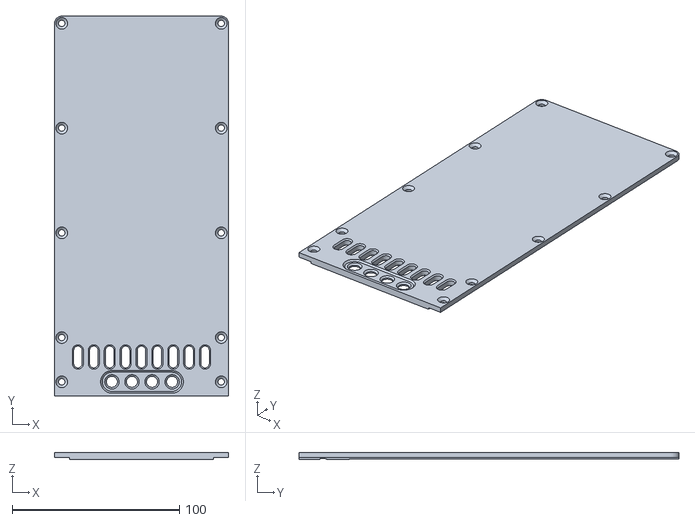
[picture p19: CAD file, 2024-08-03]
3DModels/MYNOVA-SmartPower_STL/Full-Top.stl
104.0 x 227.0 x 4.10

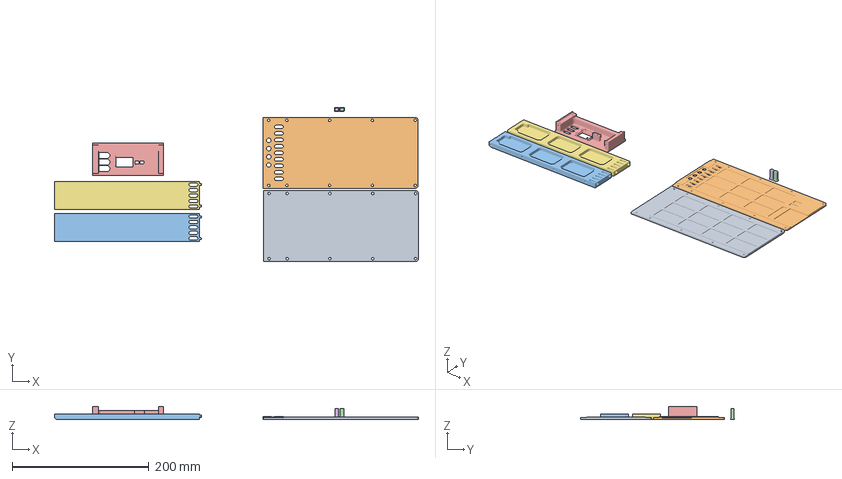
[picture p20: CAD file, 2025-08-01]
3DModels/MYNOVA-SmartPower-Color.3mf
532.6 x 225.6 x 19.2 mm
Full-Bottom.stl
Full-Top.stl
Full-Slide-L-Logo.stl
Full-Btn_Right.stl x 2
Full-Front.stl
Full-Slide-R-Logo.stl

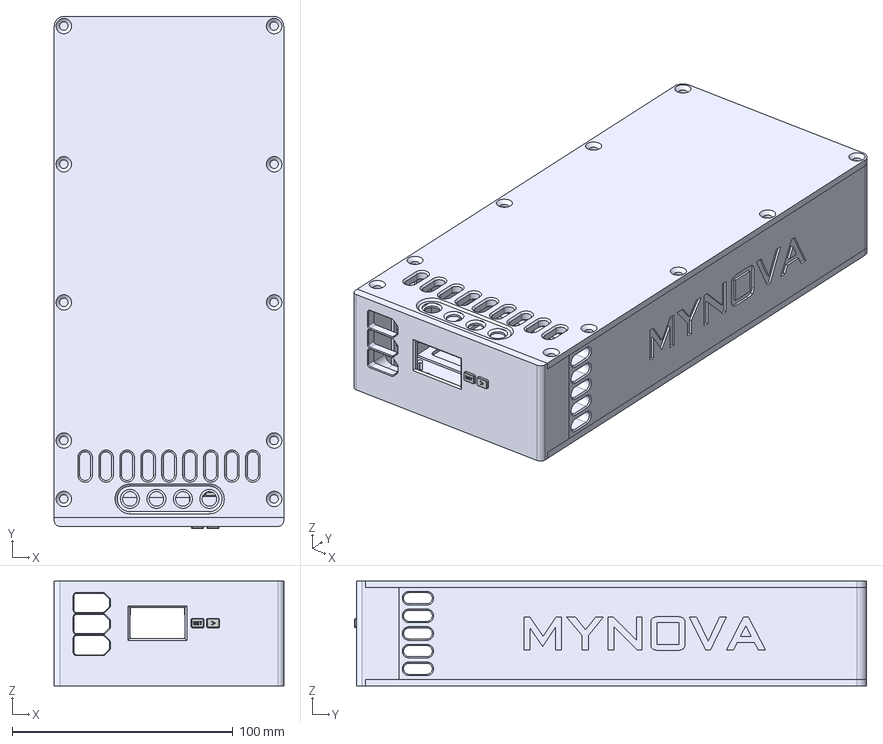
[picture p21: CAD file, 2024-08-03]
3DModels/MYNOVA-SmartPower.step
104.0 x 232.0 x 47.5 mm

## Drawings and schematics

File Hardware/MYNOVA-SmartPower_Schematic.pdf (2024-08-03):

P18 P18 P19 P19 P20 P20 P21 P21 P22 P22 P23 P23 P24 P24 P25 P25 P26 P26 P27 P27 P28 P28 P29 P29 P30 P30 P31 P31 P32 P32 P33 P33 P34 P34 P35 P35 P36 P36

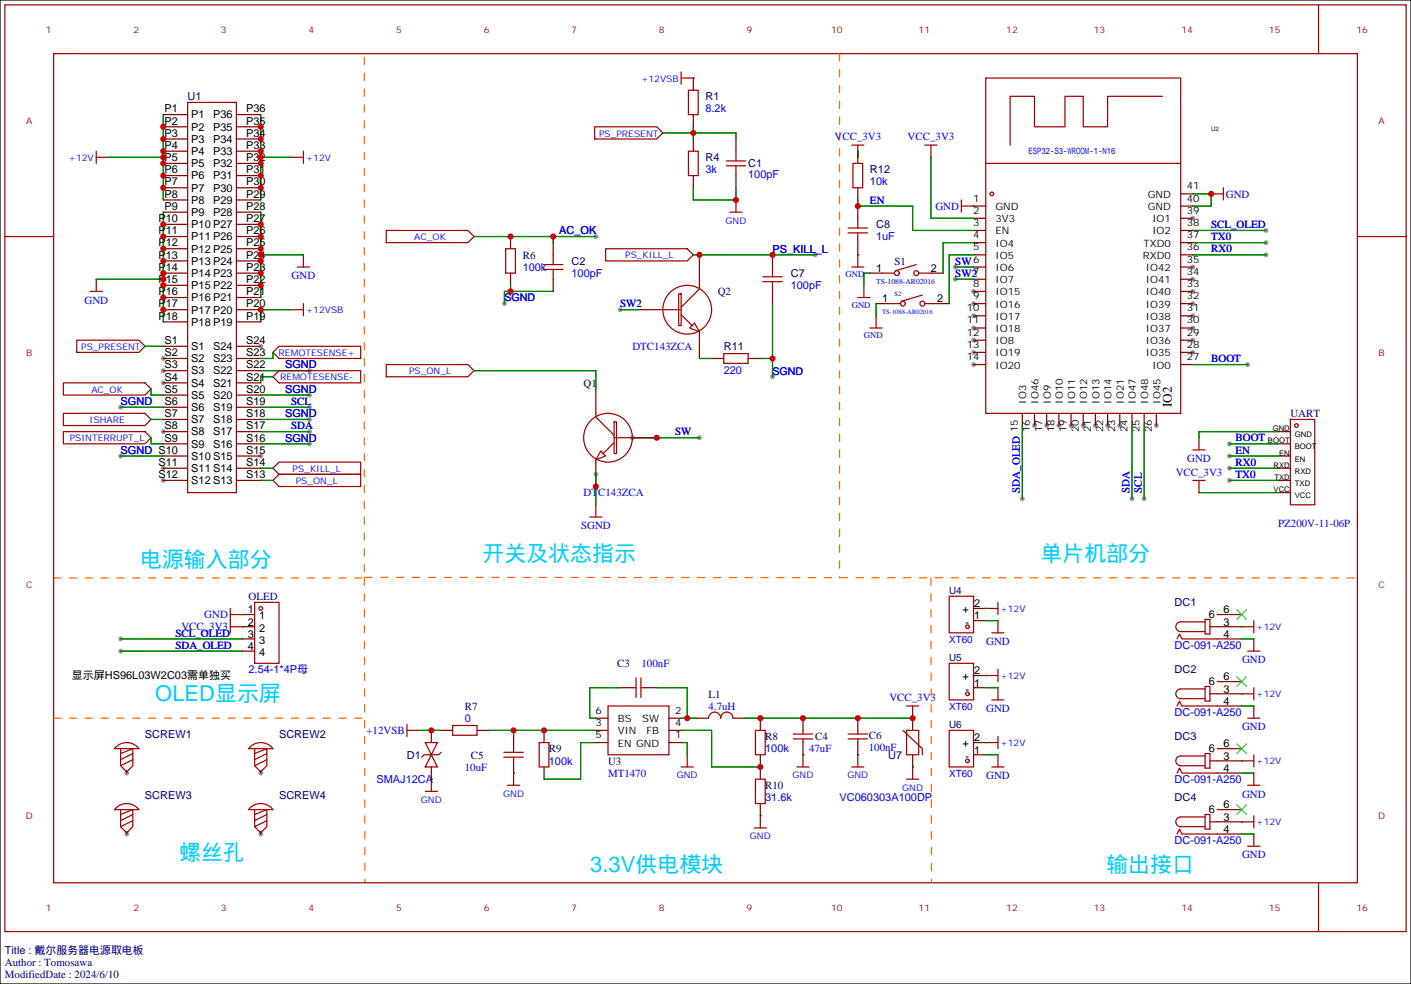
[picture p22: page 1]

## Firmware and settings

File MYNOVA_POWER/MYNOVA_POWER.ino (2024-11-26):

/*
 Name:		MYNOVA_POWER.ino
 Created:	2024/1/22 13:40:30
 Author:	Tomosawa
 GitHub:    https://github.com/Tomosawa/MYNOVA-SmartPower
*/
#pragma GCC diagnostic warning "-Wunused-variable"

#include <Arduino.h>
#include <Wire.h>
#include "multi_button.h"
#include "pmbus.h"
#include "GUIRender.h"
#include "WIFINetwork.h"
#include "WebService.h"
#include "ButtonHandle.h"
#include "IOPIn.h"
#include "Settings.h"
#include "Version.h"
#include "PageTimer.h"
#include "TimeSync.h"
#include "TaskManager.h"
//类声明
PMBus psu;
GUIRender guiRender;
WIFINetwork wifiNetwork;
WebService webService;
ButtonHandle buttonHandle;
Settings settings;
PageTimer pageTimer;
TimeSync timeSync;
TaskManager taskManager;
//全局变量
//开机确认页面[-1]关机确认页面[-2]风扇速度设置[4]
//关机OFF页面[0]输入输出页面[1]温度风扇[2]网络信息[3]
int displayPage = 0;
bool powerOn = false;
u_long pageTimeOut = 5000;//页面超时5s
//是否扫描WIFI中
bool bScanWifi = true;

//程序初始化
void setup()
{
    Serial.begin(115200);
    
    //版本信息
    String version_info = "MYNOVA Firmware " + String(FIRMWARE_VERSION) + " \r\nBuild " + String(__DATE__);
    Serial.println(version_info);

    //I2C PMBus initial
    Serial.println("I2C PMBus initial Wire.begin");
    Wire1.begin(PIN_PMBUS_SDA, PIN_PMBUS_SCL, I2C_PMBUS_CLOCK);

    //按钮初始化
    buttonHandle.init();
    
    // Read Settings
    settings.ReadSettings();

    // Init PSU
    Serial.println("Init PSU and read info");
    psu.init(PIN_SW_PSON, PIN_SW_PSKILL, &Serial, &Wire1);

    // Display Init
    Serial.println("OLED GUI Init");
    guiRender.init();
    
    //WIFI初始化
    Serial.println("WIFI Network Init");
    wifiNetwork.init();
   
    //异步扫描WIFI
    WiFi.scanNetworks(true);

    //开机是否启动电源
    if(settings.AC_PowerON)
    {
        psu.on();
    }

    // 初始化任务管理器    
    taskManager.setGetValueCallback([](ConditionType type, ConditionQuantity quantity) -> float {
        switch(type) {
            case ConditionType::TYPE_INPUT:
                return quantity == ConditionQuantity::QUANTITY_CURRENT ? psu.I_in : psu.W_in;
            case ConditionType::TYPE_OUTPUT:
                return quantity == ConditionQuantity::QUANTITY_CURRENT ? psu.I_out : psu.W_out;
            default:
                return 0.0f;
        }
    });
    
    // 恢复保存的任务
    //settings.RestoreTasks(taskManager);

    // 根据WiFi设置决定任务还原时机
    if (!settings.enable_ST || settings.ST_ssid.isEmpty()) {
        // 如果未启用WiFi或没有配置WiFi，直接还原任务
        Serial.println("WiFi disabled, restore tasks immediately");
        settings.RestoreTasks(taskManager);
    } else {
        // 如果启用了WiFi，等待时间同步后再还原任务
        Serial.println("WiFi enabled, will restore tasks after time sync");
        // 在时间同步完成后的回调中还原任务
        timeSync.setTimeSyncCallback([]() {
            Serial.println("Time synced, restoring tasks");
            settings.RestoreTasks(taskManager);
        });
    }
    
    // 启动任务管理器
    taskManager.start();

    Serial.println("\r\n===setup() complete===\r\n");
    Serial.print("WIFI Scan.");
}
/*
 * 初始化WIFI、AP、Web服务，在扫描WIFI完成后调用
 */
void InitWIFIAPService()
{
    bool bStartWebService = false;
    //启动WIFI
    if(settings.enable_ST && !settings.ST_ssid.isEmpty())
    {
        Serial.println("WIFI ST Enabled\nStart Connect WIFI\nSSID:"+settings.ST_ssid+"\nPWD:"+settings.ST_password);
        wifiNetwork.startWIFI();
        bStartWebService = true;
    }
    else
    {
        Serial.println("WIFI ST Disabled");
    }
    
    wifiNetwork.wifi_json = wifiNetwork.getAllSSIDJson();

    //启动热点
    if(settings.enable_AP && !settings.AP_ssid.isEmpty() && !settings.AP_password.isEmpty())
    {
        Serial.println("WIFI AP Started");
        wifiNetwork.startAP();
        bStartWebService = true;
    }
    else
    {
        Serial.println("WIFI AP Disabled");
    }

    //初始化 启动Web服务器
    Serial.println("WebService Start");
    webService.init(wifiNetwork.getAPIP(), &wifiNetwork, &psu);
    webService.serverStart();
}

/*
 * 程序循环
 */
void loop()
{
    if(bScanWifi)
    {
        Serial.print(".");
        int networksCount = WiFi.scanComplete();
        if(networksCount >= 0)
        {
            Serial.print("\nWIFI Scan OK. Count:");
            Serial.println(networksCount);
            bScanWifi = false;
            InitWIFIAPService();
            
        }else if(networksCount == WIFI_SCAN_FAILED)
        {
            Serial.println("\nWIFI Scan Failed");
            bScanWifi = false;
            InitWIFIAPService();
        }
        delay(500);
        yield();
    }
    //时间同步
    if (WiFi.status() == WL_CONNECTED && !timeSync.timeSynced) {
        timeSync.checkIfNeedSync();
    }
   
    if (psu.scan())
    {
        Serial.println("PSU Scan OK");
        //判断电源是否启动
        bool bState = psu.checkOnOffState();

        //与之前状态有变化，进行处理
        if(powerOn != bState)
        {
            //记录状态
            powerOn = bState;
            if(powerOn){
                psu.recordTurnOnTime();
                //输入输出页面[1]
                displayPage = 1;
            }
            else
            {
                //关机OFF页面[0]
                displayPage = 0;
            }
        }

        guiRender.setValues(&psu,&wifiNetwork);
    }

    //风扇设置页面[4]:超时计时
    if(displayPage == 4)
    {
      if(pageTimer.checkTimeOut(pageTimeOut))
      {
        //返回->温度风扇页面[2]
        displayPage = 2;
      }
    }

    yield();
    guiRender.drawOLED(displayPage);

    yield();
    webService.processRequest();

    yield();

    //delay(100);
}

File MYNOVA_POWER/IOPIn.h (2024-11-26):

/*
 * Copyright (c) 2024 Tomosawa
 * https://github.com/Tomosawa/
 * All rights reserved
 */
#ifndef H_IOPIN_H
#define H_IOPIN_H

//针脚定义
#define PIN_BUTTON_L    4
#define PIN_BUTTON_R    5
#define PIN_SW_PSON     6
#define PIN_SW_PSKILL   7
#define PIN_KILL        45
#define PIN_PMBUS_SCL   48
#define PIN_PMBUS_SDA   47
#define PIN_AC_OK       10

#endif

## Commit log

2024-08-03 V1.0 release
    V1.0 release
    [MYNOVA_16MB.csv, MYNOVA_8MB.csv]
2024-08-03 Submit hardware-related materials and 3D model files.
    This submission includes hardware schematics (including Altium Designer and PADS files), PCB Gerber files, and 3D model files for the casing.
    [1_P1.schdoc, Full-Bottom.stl, Full-Btn_Left.stl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]
2024-12-02 V1.1.1
    fix exponent bug
    [pmbus.cpp]
2025-08-01 added 3mf file
    Added sliced 3MF file for 3D multicolor printing.
    [MYNOVA-SmartPower-Color.3mf]
